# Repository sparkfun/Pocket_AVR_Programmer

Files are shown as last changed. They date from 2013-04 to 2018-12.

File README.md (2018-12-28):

Pocket AVR Programmer
=====================

[Pocket AVR Programmer  
*Pocket AVR Programmer (PGM-09825)*](https://www.sparkfun.com/products/9825)

This is a simple to use USB AVR programmer, that works with ATmega168 and ATmega328 and should work well
with all the AVR micros supported by AVRDUDE.

Repository Contents
-------------------
* **/Enclosure** - 3D model of enclosure for this (.stl).
* **/Drivers** - Windows 7 drivers for use with this programmer. 
* **/Firmware** - Firmware that ships on the Pocket AVR Programmer.
* **/Hardware** - All Eagle design files (.brd, .sch).

Documentation
--------------
* **[Hookup Guide](https://learn.sparkfun.com/tutorials/pocket-avr-programmer-hookup-guide)** - Basic hookup guide for the Pocket AVR Programmer. 
* **[Installing an Arduino Bootloader](https://learn.sparkfun.com/tutorials/installing-an-arduino-bootloader)**  - Example of installing an Arduino bootloader on an Atmega328P-based microcontrollers (i.e. Arduino Uno and RedBoard Programmed with Arduino) through the Arduino IDE and command line using avrdude.

License Information
-------------------
The hardware is released under [Creative Commons Share-alike 3.0](http://creativecommons.org/licenses/by-sa/3.0/).
The firmware is based off of:
* [USBtiny](http://dicks.home.xs4all.nl/avr/usbtiny/index.html) by Dick Streefland
* [USBtinyISP](http://www.ladyada.net/make/usbtinyisp/) by Limor Fried and is a collaboration with Limor Fried currently.

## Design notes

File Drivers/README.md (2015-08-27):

Pocket AVR Programmer Drivers
=============================

Folder Contents
-------------------
Windows 7, 8, 8.1, 10 Driver files for the AVR Pocket Programmer. Original Source of files: http://www.adafruit.com/downloads/usbtiny_signed_8.zip

Please note you no longer need to verify the security signature for the drivers.

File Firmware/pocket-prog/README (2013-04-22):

USBtiny
=======

USBtiny is a software implementation of the USB low-speed protocol for
the Atmel ATtiny microcontrollers. Of course, it will also work on the
ATmega series. The software is written for an AVR clocked at 12 MHz.
At this frequency, each bit on the USB bus takes 8 clock cycles, and
with a lot of trickery, it is possible to decode and encode the USB
waveforms by software. The USB driver needs between 1300 and 1400
bytes of flash space (excluding the optional identification strings),
depending on the configuration and compiler version, and 46 bytes RAM
(excluding stack space). The C interface consists of 3 to 5 functions,
depending on the configuration.

Implementation
==============

USB uses two differential data signals, D+ and D-, which are normally
complementary. However, the end of a packet is signalled by pulling
both signals low. Data is not transmitted directly on the USB bus, it
is NRZI encoded first. This means that a "0" bit is encoded as a bit
change, and a "1" bit is encoded as no bit change. After 6 "1" bits,
"bit stuffing" takes place to force a change on the USB signal lines.

The software is interrupt driven: the start of a USB packet triggers
an interrupt. The interrupt handler synchronizes with the sync byte,
removes the NRZI encoding and bit stuffing, and stores the packed in
one of the two RAM buffers. Two buffers are used so that the next
packet can be received while the current one is being processed.
Depending on the packet type, a reply packed may be sent back
immediately in the interrupt handler.

The rest of the USB driver is written in C. A usb_poll() function
must to be called periodically to poll for incoming packets. Only a
single endpoint is supported at the moment. Standard control requests
are directly handled by the USB driver. Other SETUP requests are
forwarded to a user-supplied function usb_setup(). Support for large
replies and OUT control requests is optional, see usbtiny.h.

To use the USB driver in your own application, you need to configure
the macros in usbtiny.h, and provide a function usb_setup() to handle
SETUP control packets. Optionally, you need to provide the functions
usb_in() and usb_out(). Your code needs to call the initialization
function usb_init() at program startup, and usb_poll() at regular
intervals. The AVR device type and the upload command should be
configured at the top of the Makefile.

Other USB projects
==================

This software was inspired by two similar USB projects for the AVR:

  http://www.cesko.host.sk/IgorPlugUSB/IgorPlug-USB%20(AVR)_eng.htm
  http://www.obdev.at/products/avrusb/index.html

My version has the advantage that you have more freedom over which I/O
pins to use for the D+ and D- USB signals. You don't need to use bit 0
for the D+ signal. The only restriction is that both signals should be
on the same I/O port. When you select a pin for D+ that can also
generate an interrupt, only two I/O pins are required. The pin-change
interrupt is deliberately not used, so that it remains available for
other uses.

Another improvement is that the CRC calculation is faster, because it
uses a lookup table. A bit-wise calculation turned out to be too slow
for the USB controller in my laptop. For instance, the obdev code
worked fine on my desktop computer, but not on my laptop.

Apart from these advantages, I think that my code is more readable and
easier to configure, but that impression may be caused by a mild form
of the NIH syndrome that I'm suffering from. In any case, I learned a
lot about the USB protocol, and writing the interrupt handler was a
nice puzzle.

Hardware
========

The AVR must be clocked with an external 12 MHz crystal. For an
ATtiny2313, this means that the low fuse byte must be reprogrammed,
for instance to 0xff. I also recommend to enable the BOD circuit,
when available. For the ATtiny2313, this means programming the high
fuse byte to 0xdb (BOD level is 2.7V).

The USB data signals are specified at 3.3V. The easiest way to
accomplish this is to use a 3.3V power supply for the AVR. However,
driving the USB signals with 5V seems to work as well in most cases,
which may be more convenient when you need to interface to 5V
peripherals. According to the USB specification, a device should not
be damaged by 5V signals. I've been running the AVR and USB bus at 5V,
and haven't encounter any problems so far, but I have some reports
of Viao laptops that do not work with 5V signals. In that case, you
can reduce the voltage of the USB data signals by adding 3V6 zener
diodes from the data signals to ground.

USBtiny SPI converter
=====================

My first USBtiny application is a USB to SPI (Serial Programming
Interface) converter. The SPI signals are connected to a female DB-25
connecter, so that the converter can be plugged onto my AVR parallel
port programmer. Because the most important parallel port signals are
connected to the DB-25 connecter, the same hardware (with different
firmware) could be used to control other parallel port devices. That
is also the reason why I connected the ACK signal to the INT1 pin.
I didn't bother to put capacitors on the crystal, but they are
recommended for reliable operation. The software, the schematic and
a Python test script can be found in the "spi" subdirectory.

The circuit may be powered via the diode at pin 14 of the DB-25
connector to enable reprograming the ATtiny2313 in-system. This
requires an adaptor cable between another SPI programmer and a DB-25
male connector with the following connections:

  SPI  DB25
  ---  ----
  GND    25
  VCC    14
  RESET  13
  SCK     9
  MISO    8
  MOSI    7

Bit-banging the SPI signals via USB turned out to be very slow. To get
reasonable programming speeds, I've moved the SPI algorithm into the
AVR. This means that you can send a 32-bit SPI command in a single USB
packet. In addition, you can read or write up to 255 bytes from/to
flash or EEPROM in a single control transfer.

The subdirectory "patches" contains a patch for avrdude-5.1 that adds
support for controlling this SPI converter. The programmer name is
"usbtiny". You can use the -B option or the "sck" command to specify
the minimum SCK period in microseconds (range: 1..250, default: 10).

USBtiny LIRC compatible IR receiver and LCD controller
======================================================

A second USBtiny application is a receiver for infrared remote
controls that can be used with the LIRC package (http://www.lirc.org/).
The firmware stores the mark/space timings from a TSOP1738 IR decoder
in a buffer that is polled by a LIRC device driver. As a visual
feedback, a LED is flashed when a signal is being received. As an
additional (optional) feature, a 2x16 LCD display is attached to PORTB.
You can control the display via the USB bus. The software, the schematic
and a Python test script can be found in the "ir" subdirectory.
A pull-down resistor at PB3 prevents a hang in the LCD initialization
code when no LCD is attached to PORTB. You can disable the LCD code by
setting the LCD_PRESENT macro in main.c to 0.

I adopted the "IgorPlug-USB" protocol, so that the existing LIRC
device driver "igorplugusb" could be used without modifications.
Nevertheless, a patch for lirc-0.8.0 is included in the "patches"
subdirectory, with the following modifications:
1) An increase of the sample rate from 10 to 100 times per second.
   This is not required, but improves the responsiveness and repeat
   behavior for some remote controls.
2) A fix from Reinhard Max to get correct gap timings.
3) A compilation fix for the latest 2.6 Linux kernels.

Tools
=====

The software was developed on a Linux system. In addition to standard
tools like GNU make, you need the AVR versions of gcc, binutils and
glibc to build the code: On a Debian/Ubuntu system, you can apt-get
the following packages:

  gcc-avr
  binutils-avr
  avr-libc

To upload the code to an AVR, I use avrdude with a parallel port
programmer.

I initially used gcc-3.4.3 with the -Os option, which generates
reasonable compact code. Unfortunately, newer versions like gcc-4.1.0
generate about 10% more code, and as a result, the application code
did not fit in 2K anymore. To make it fit, I had to remove the optional
vendor and device strings, by undefining the USBTINY_VENDOR_NAME and
USBTINY_DEVICE_NAME macros.

The schematics were created with gschem, which is part of the gEDA
package. The conversion to Postscript is done with a script that
invokes gschem non-interactively.

The "util" and application code subdirectories each contain their own
Makefile. In addition, there is a global Makefile that recursively
invokes all other Makefiles.

Host software
=============

The subdirectory "utils" contains a Python module "usbtiny.py" that
defines a class USBtiny that can be used to communicate with the
USBtiny firmware. This class is used by the test scripts.

The usbtiny.py module uses a Python wrapper around libusb that is
generated by "swig". Type "make" to build the wrapper. Of course, you
need to have swig, libusb and libusb-dev installed on your system.

Libusb needs appropriate permissions to open a USB device. This means
that you either have to run the scripts as "root", or you should
configure the hotplug or udev system to relax the permissions of the
device file created under /proc/bus/usb/ when the device is plugged
in. With udev, you can change the permissions by adding a rule like

  SUBSYSTEM=="usb_device", MODE="0666" 

to the udev rules in /etc/udev/rules.d/

License
=======

The USBtiny software is licensed under the terms of the GNU General
Public License as published by the Free Software Foundation, either
version 2 of the license, or (at your option) any later version. A
copy of the GPL version 2 license can be found in the file COPYING.

Author & website
================

Dick Streefland <dick@streefland.net>

http://www.google.com/search?btnI&q=webtag_net_streefland_avr_usbtiny

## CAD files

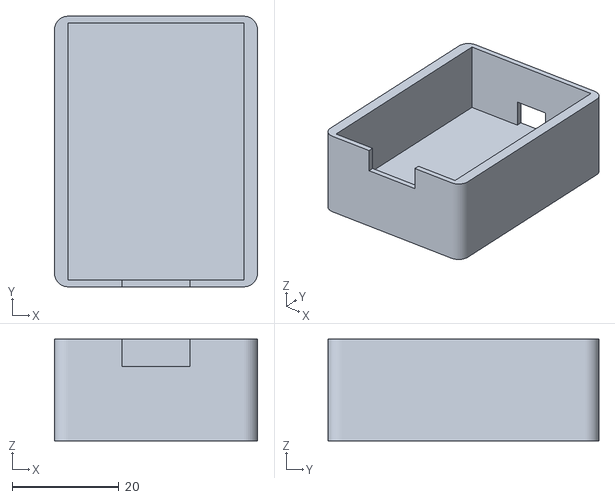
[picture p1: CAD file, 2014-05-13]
Enclosure/avr.STL
38.1 x 50.8 x 19.1

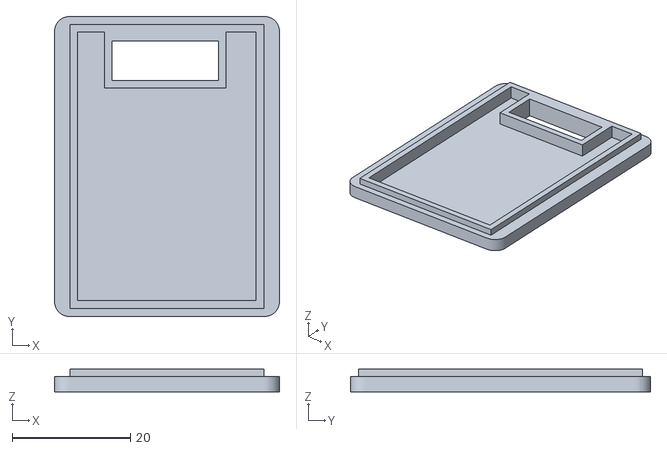
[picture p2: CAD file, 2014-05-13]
Enclosure/lid.STL
38.1 x 50.8 x 3.81

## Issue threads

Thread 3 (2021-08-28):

Error when trying to compile  Pocket_AVR_Programmer firmware

hansake, 2021-08-28:
When trying to compile the Pocket_AVR_Programmer firmware I get:
~/AVR/Pocket_AVR_Programmer-master/Firmware/pocket-prog/spi$ make all
avr-gcc -Os -g -Wall -I. -I../usbtiny  -mmcu=attiny2313 -c ../usbtiny/crc.S
In file included from ../usbtiny/crc.S:22:0:
../usbtiny/def.h:39:13: error: attempt to use poisoned "SIG_INT0"
 #if defined SIG_INT0
             ^
make: *** [../usbtiny/common.mk:56: crc.o] Error 1

I am using gcc/avr/5.4.0
Any idea what is wrong?
/Hans-Åke

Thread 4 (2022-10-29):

3.3 V and 5 V tolerant design

gsauthof, 2022-10-29:
Reading through the Sparkfun hook-up guide I was surprised to find a recommendation for a Sparkfun Logic Level Converter since the original schematics read like it would be superfluous. I left a comment under the [guide](https://learn.sparkfun.com/tutorials/pocket-avr-programmer-hookup-guide/discuss) and was recently informed that this issue tracker would be a better place for such feedback.

For reference my comment (posted it in May 2022):

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

---

I also asked about this on the Electronics SE site. I think that the [answer of User 'Justme'](https://electronics.stackexchange.com/a/623231) contains some additional useful feedback you might want to consider in a future hardware revision.

I'll reproduce the relevant part here, even if the tone is a bit harsh, since the raised points might still be of interest to you:

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

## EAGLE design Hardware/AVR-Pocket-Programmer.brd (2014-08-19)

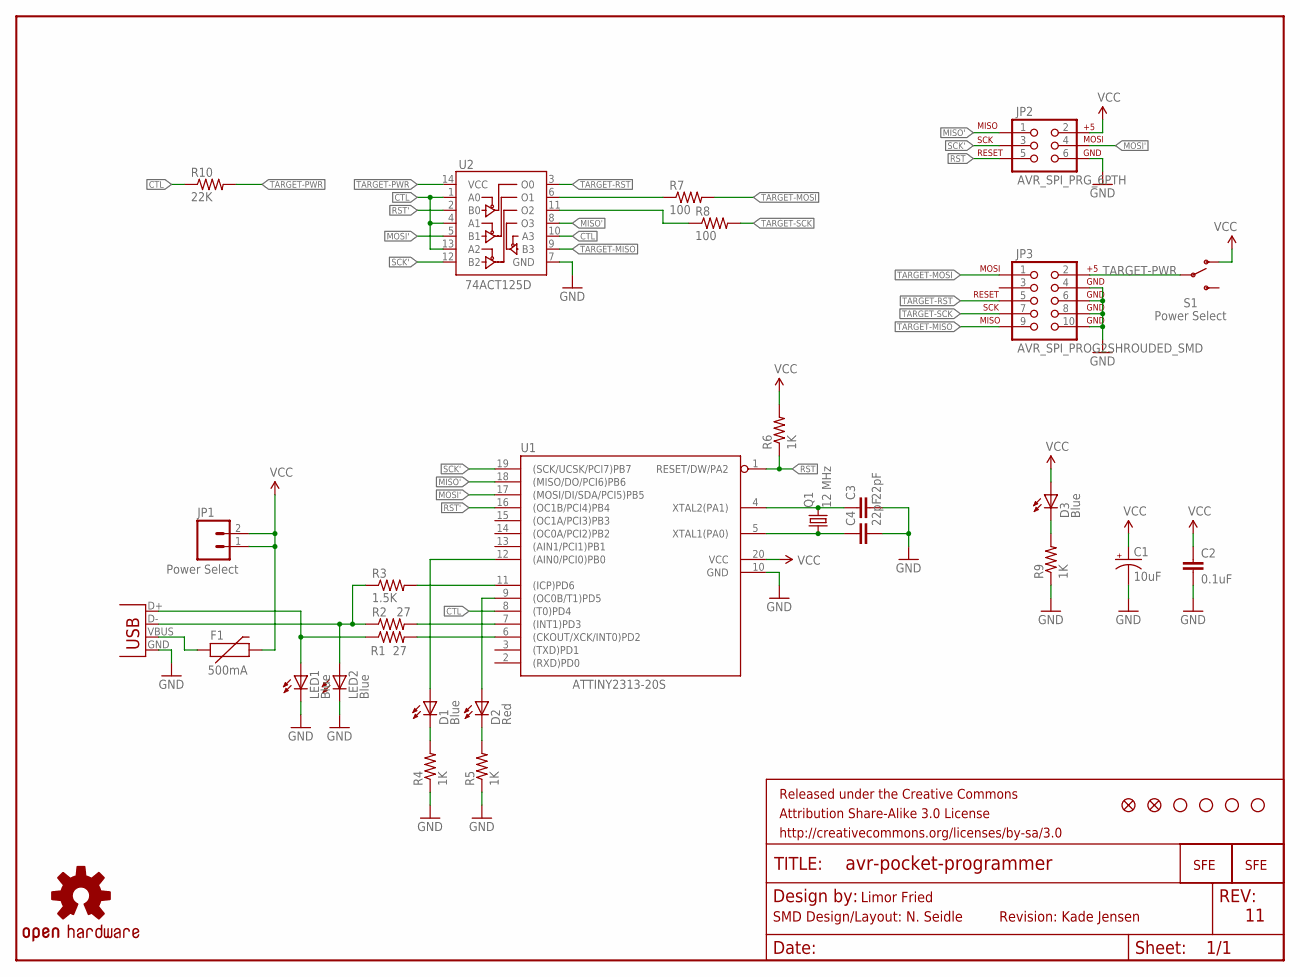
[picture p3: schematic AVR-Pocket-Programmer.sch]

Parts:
C1: 10uF; EIA3216
C2: 0.1uF; 0603-CAP
C3, C4: 22pF; 0603-CAP
D1, D3: Blue; LED-0603
D2: Red; LED-0603
F1: 500mA; PTC-1206-WIDE
FRAME1: FRAME-LETTER; CREATIVE_COMMONS
JP1: Power Select; 1X02
JP2: AVR_SPI_PRG_6PTH; 2X3
JP3: AVR_SPI_PROG2SHROUDED_SMD; 2X5-SHROUDED_SMD
LED1, LED2: Blue; LED-0603
LOGO1: OSHW-LOGOM; OSHW-LOGO-M
Q1: 12 MHz; CRYSTAL-SMD-5X3
R1, R2: 27; 0603-RES
R3: 1.5K; 0603-RES
R4, R5, R6, R9: 1K; 0603-RES
R7, R8: 100; 0603-RES
R10: 22K; 0603-RES
S1: Power Select; AYZ0202
U1: ATTINY2313-20S; SO20L
U2: 74ACT125D; SO014
U$1, U$3, U$4, U$5: STAND-OFF
U$2: LOGO-SFESK; SFE-LOGO-FLAME
U$6, U$7: FIDUCIAL1X2; FIDUCIAL-1X2
U$8: LOGO-SFENEW; SFE-NEW-WEBLOGO
X2: USBSMD; USB-MINIB

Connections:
CTL: R10.1, U1.8 ((T0)PD4), U2.1 (A0), U2.4 (A1), U2.10 (A3), U2.13 (A2)
D+: LED1.A, R1.1, X2.D+
D-: LED2.A, R2.1, R3.1, X2.D-
GND: C1.C (-), C2.2, C3.2, C4.2, JP2.6, JP3.4, JP3.6, JP3.8, JP3.10, LED1.C, LED2.C, R4.1, R5.1, R9.1, U1.10 (GND), U2.7 (GND), X2.GND
MISO': JP2.1, U1.18 ((MISO/DO/PCI6)PB6), U2.8 (O3)
MOSI': JP2.4, U1.17 ((MOSI/DI/SDA/PCI5)PB5), U2.5 (B1)
unnamed: R3.2, U1.11 ((ICP)PD6)
unnamed: D2.A, U1.9 ((OC0B/T1)PD5)
unnamed: D3.C, R9.2
unnamed: F1.1, X2.VBUS
unnamed: C3.1, Q1.3 (2), U1.4 (XTAL2(PA1))
unnamed: C4.1, Q1.1, U1.5 (XTAL1(PA0))
unnamed: D1.A, U1.12 ((AIN0/PCI0)PB0)
unnamed: D1.C, R4.2
unnamed: D2.C, R5.2
unnamed: R7.1, U2.6 (O1)
unnamed: R8.1, U2.11 (O2)
PD+: R1.2, U1.6 ((CKOUT/XCK/INT0)PD2)
PD-: R2.2, U1.7 ((INT1)PD3)
RST: JP2.5, R6.1, U1.1 (RESET/DW/PA2)
RST': U1.16 ((OC1B/PCI4)PB4), U2.2 (B0)
SCK': JP2.3, U1.19 ((SCK/UCSK/PCI7)PB7), U2.12 (B2)
TARGET-MISO: JP3.9, U2.9 (B3)
TARGET-MOSI: JP3.1, R7.2
TARGET-PWR: JP3.2, R10.2, S1.2, U2.14 (VCC)
TARGET-RST: JP3.5, U2.3 (O0)
TARGET-SCK: JP3.7, R8.2
VCC: C1.A (+), C2.1, D3.A, F1.2, JP1.1, JP1.2, JP2.2, R6.2, S1.1 (O), U1.20 (VCC)

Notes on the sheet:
Limor Fried
SMD Design/Layout: N. Seidle
Revision: Kade Jensen

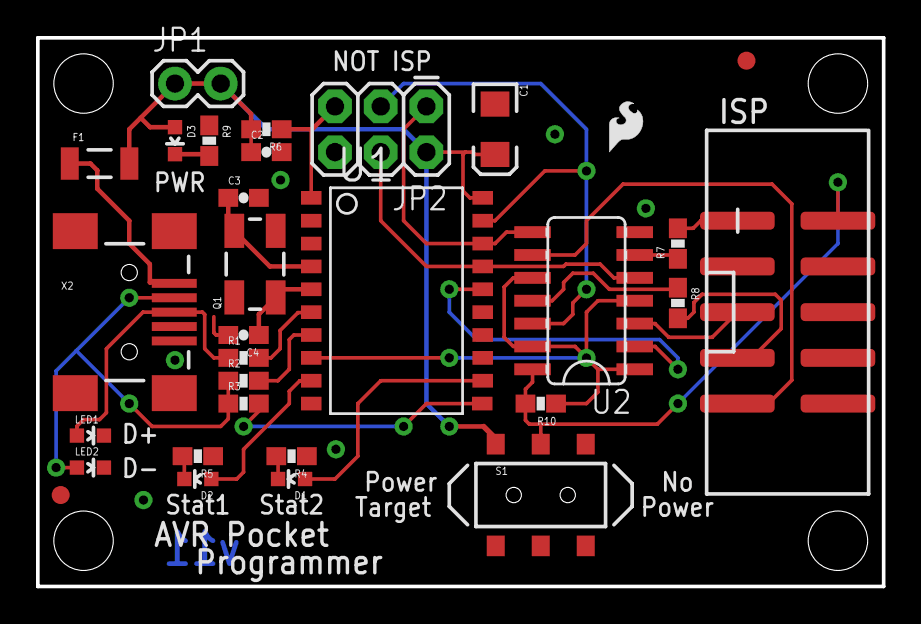
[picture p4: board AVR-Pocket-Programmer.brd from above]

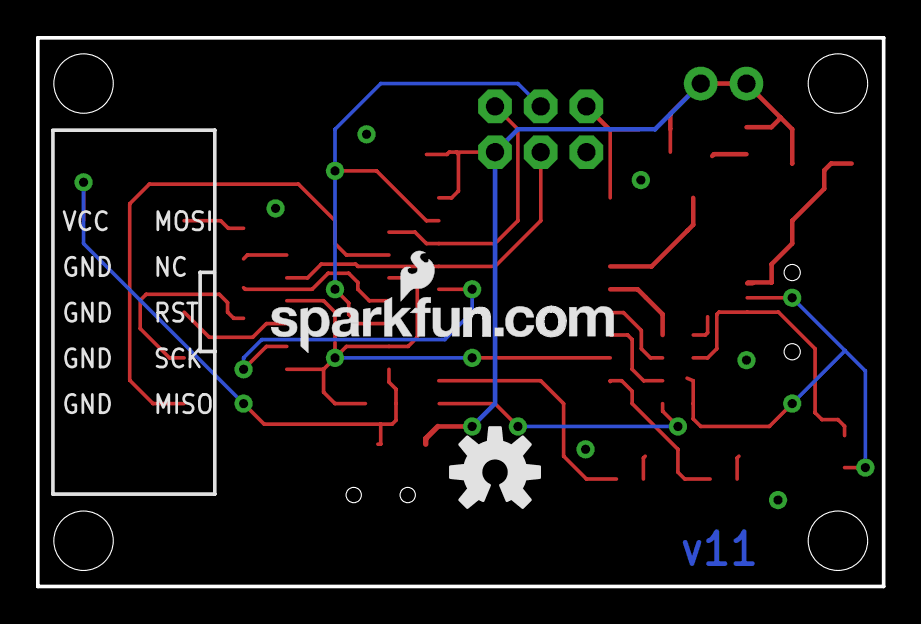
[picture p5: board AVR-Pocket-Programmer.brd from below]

Board: 2 copper layers, 47.0 x 30.5 mm, 38 parts (2 on the bottom side), 28 nets.

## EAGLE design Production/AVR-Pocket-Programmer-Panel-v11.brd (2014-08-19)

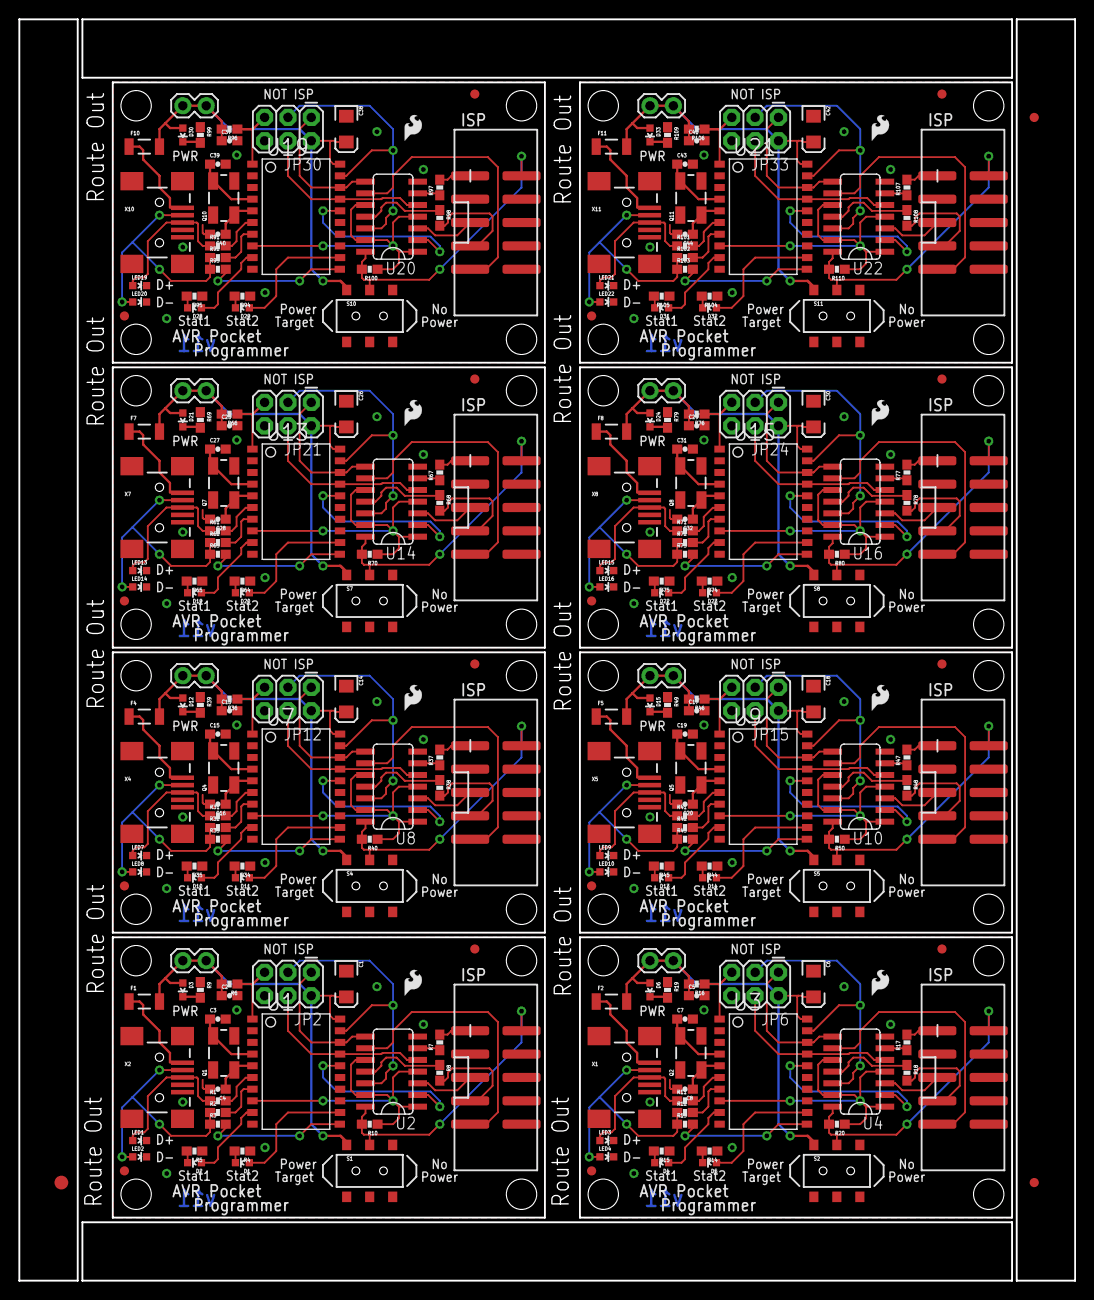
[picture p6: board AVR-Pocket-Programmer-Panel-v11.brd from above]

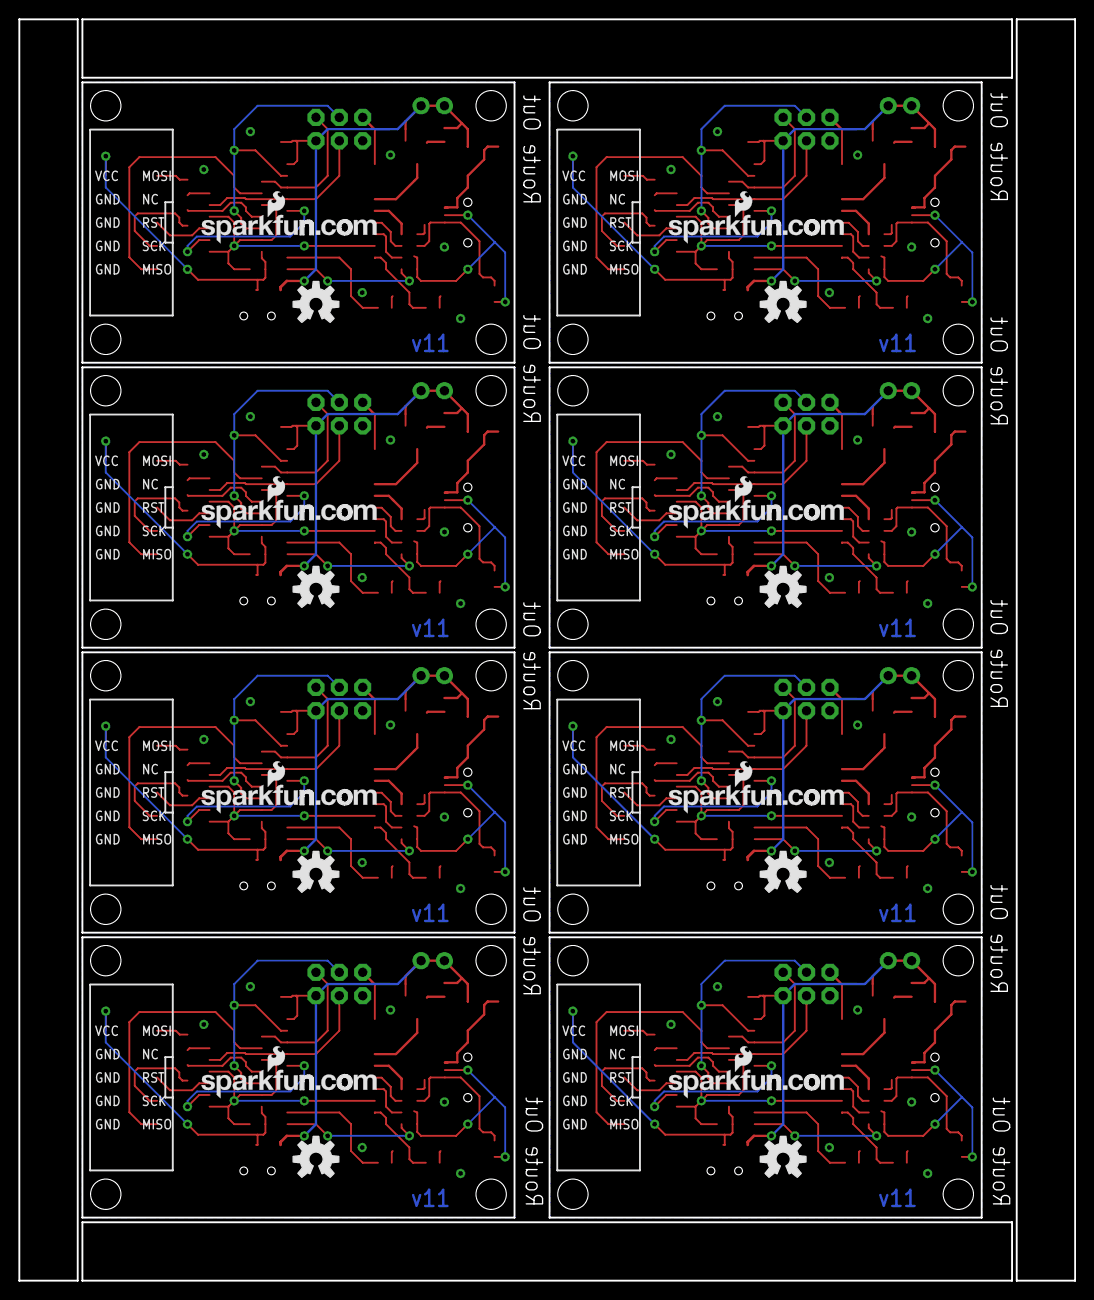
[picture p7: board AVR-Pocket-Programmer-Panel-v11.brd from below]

Board: 2 copper layers, 114.8 x 137.2 mm, 299 parts (16 on the bottom side), 224 nets.

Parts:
C1, C6, C14, C18, C26, C30, C38, C42: 10uF; EIA3216
C2, C5, C13, C17, C25, C29, C37, C41: 0.1uF; 0603-CAP
C3, C4, C7, C8, C15, C16, C19, C20, C27, C28, C31, C32, C39, C40, C43, C44: 22pF; 0603-CAP
D1, D3, D5, D6, D11, D12, D14, D15, D20, D21, D23, D24, D29, D30, D32, D33: Blue; LED-0603
D2, D4, D10, D13, D19, D22, D28, D31: Red; LED-0603
E$1: FIDUCIAL-1.5X3
E$5, E$6: FIDUCIAL-1X2
F1, F2, F4, F5, F7, F8, F10, F11: 500mA; PTC-1206-WIDE
JP1, JP4, JP10, JP13, JP19, JP22, JP28, JP31: Power Select; 1X02
JP2, JP6, JP12, JP15, JP21, JP24, JP30, JP33: AVR_SPI_PRG_6PTH; 2X3
JP3, JP5, JP11, JP14, JP20, JP23, JP29, JP32: AVR_SPI_PROG2SHROUDED_SMD; 2X5-SHROUDED_SMD
LED1, LED2, LED3, LED4, LED7, LED8, LED9, LED10, LED13, LED14, LED15, LED16, LED19, LED20, LED21, LED22: Blue; LED-0603
LOGO1, LOGO2, LOGO4, LOGO5, LOGO7, LOGO8, LOGO10, LOGO11: OSHW-LOGOM; OSHW-LOGO-M
Q1, Q2, Q4, Q5, Q7, Q8, Q10, Q11: 12 MHz; CRYSTAL-SMD-5X3
R1, R2, R11, R12, R31, R32, R41, R42, R61, R62, R71, R72, R91, R92, R101, R102: 27; 0603-RES
R3, R13, R33, R43, R63, R73, R93, R103: 1.5K; 0603-RES
R4, R5, R6, R9, R14, R15, R16, R19, R34, R35, R36, R39, R44, R45, R46, R49, R64, R65, R66, R69, R74, R75, R76, R79, R94, R95, R96, R99, R104, R105, R106, R109: 1K; 0603-RES
R7, R8, R17, R18, R37, R38, R47, R48, R67, R68, R77, R78, R97, R98, R107, R108: 100; 0603-RES
R10, R20, R40, R50, R70, R80, R100, R110: 22K; 0603-RES
S1, S2, S4, S5, S7, S8, S10, S11: Power Select; AYZ0202
U1, U3, U7, U9, U13, U15, U19, U21: ATTINY2313-20S; SO20L
U2, U4, U8, U10, U14, U16, U20, U22: 74ACT125D; SO014
U$1, U$3, U$4, U$5, U$9, U$10, U$11, U$12, U$25, U$26, U$27, U$28, U$33, U$34, U$35, U$36, U$49, U$50, U$51, U$52, U$57, U$58, U$59, U$60, U$73, U$74, U$75, U$76, U$81, U$82, U$83, U$84: STAND-OFF
U$2, U$16, U$32, U$40, U$56, U$64, U$80, U$88: LOGO-SFESK; SFE-LOGO-FLAME
U$6, U$7, U$13, U$14, U$29, U$30, U$37, U$38, U$53, U$54, U$61, U$62, U$77, U$78, U$85, U$86: FIDUCIAL1X2; FIDUCIAL-1X2
U$8, U$15, U$31, U$39, U$55, U$63, U$79, U$87: LOGO-SFENEW; SFE-NEW-WEBLOGO
X1, X2, X4, X5, X7, X8, X10, X11: USBSMD; USB-MINIB

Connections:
CTL: R10.1, U1.8, U2.1, U2.4, U2.10, U2.13
CTL1: R20.1, U3.8, U4.1, U4.4, U4.10, U4.13
CTL3: R40.1, U7.8, U8.1, U8.4, U8.10, U8.13
CTL4: R50.1, U9.8, U10.1, U10.4, U10.10, U10.13
CTL6: R70.1, U13.8, U14.1, U14.4, U14.10, U14.13
CTL7: R80.1, U15.8, U16.1, U16.4, U16.10, U16.13
CTL9: R100.1, U19.8, U20.1, U20.4, U20.10, U20.13
CTL10: R110.1, U21.8, U22.1, U22.4, U22.10, U22.13
D+: LED1.A, R1.1, X2.D+
D+1: LED3.A, R11.1, X1.D+
D+3: LED7.A, R31.1, X4.D+
D+4: LED9.A, R41.1, X5.D+
D+6: LED13.A, R61.1, X7.D+
D+7: LED15.A, R71.1, X8.D+
D+9: LED19.A, R91.1, X10.D+
D+10: LED21.A, R101.1, X11.D+
D-: LED2.A, R2.1, R3.1, X2.D-
D-1: LED4.A, R12.1, R13.1, X1.D-
D-3: LED8.A, R32.1, R33.1, X4.D-
D-4: LED10.A, R42.1, R43.1, X5.D-
D-6: LED14.A, R62.1, R63.1, X7.D-
D-7: LED16.A, R72.1, R73.1, X8.D-
D-9: LED20.A, R92.1, R93.1, X10.D-
D-10: LED22.A, R102.1, R103.1, X11.D-
GND: C1.C, C2.2, C3.2, C4.2, JP2.6, JP3.4, JP3.6, JP3.8, JP3.10, LED1.C, LED2.C, R4.1, R5.1, R9.1, U1.10, U2.7, X2.GND
GND1: C5.2, C6.C, C7.2, C8.2, JP5.4, JP5.6, JP5.8, JP5.10, JP6.6, LED3.C, LED4.C, R14.1, R15.1, R19.1, U3.10, U4.7, X1.GND
GND3: C13.2, C14.C, C15.2, C16.2, JP11.4, JP11.6, JP11.8, JP11.10, JP12.6, LED7.C, LED8.C, R34.1, R35.1, R39.1, U7.10, U8.7, X4.GND
GND4: C17.2, C18.C, C19.2, C20.2, JP14.4, JP14.6, JP14.8, JP14.10, JP15.6, LED9.C, LED10.C, R44.1, R45.1, R49.1, U9.10, U10.7, X5.GND
GND6: C25.2, C26.C, C27.2, C28.2, JP20.4, JP20.6, JP20.8, JP20.10, JP21.6, LED13.C, LED14.C, R64.1, R65.1, R69.1, U13.10, U14.7, X7.GND
GND7: C29.2, C30.C, C31.2, C32.2, JP23.4, JP23.6, JP23.8, JP23.10, JP24.6, LED15.C, LED16.C, R74.1, R75.1, R79.1, U15.10, U16.7, X8.GND
GND9: C37.2, C38.C, C39.2, C40.2, JP29.4, JP29.6, JP29.8, JP29.10, JP30.6, LED19.C, LED20.C, R94.1, R95.1, R99.1, U19.10, U20.7, X10.GND
GND10: C41.2, C42.C, C43.2, C44.2, JP32.4, JP32.6, JP32.8, JP32.10, JP33.6, LED21.C, LED22.C, R104.1, R105.1, R109.1, U21.10, U22.7, X11.GND
MISO': JP2.1, U1.18, U2.8
MISO'1: JP6.1, U3.18, U4.8
MISO'3: JP12.1, U7.18, U8.8
MISO'4: JP15.1, U9.18, U10.8
MISO'6: JP21.1, U13.18, U14.8
MISO'7: JP24.1, U15.18, U16.8
MISO'9: JP30.1, U19.18, U20.8
MISO'10: JP33.1, U21.18, U22.8
MOSI': JP2.4, U1.17, U2.5
MOSI'1: JP6.4, U3.17, U4.5
MOSI'3: JP12.4, U7.17, U8.5
MOSI'4: JP15.4, U9.17, U10.5
MOSI'6: JP21.4, U13.17, U14.5
MOSI'7: JP24.4, U15.17, U16.5
MOSI'9: JP30.4, U19.17, U20.5
MOSI'10: JP33.4, U21.17, U22.5
unnamed: R3.2, U1.11
unnamed: D2.A, U1.9
unnamed: D3.C, R9.2
unnamed: F1.1, X2.VBUS
unnamed: C3.1, Q1.3, U1.4
unnamed: C4.1, Q1.1, U1.5
unnamed: R13.2, U3.11
unnamed: D4.A, U3.9
unnamed: D5.A, U3.12
unnamed: D5.C, R14.2
unnamed: D4.C, R15.2
unnamed: R17.1, U4.6
unnamed: R18.1, U4.11
unnamed: D6.C, R19.2
unnamed: F2.1, X1.VBUS
unnamed: C7.1, Q2.3, U3.4
unnamed: D1.A, U1.12
unnamed: D1.C, R4.2
unnamed: D2.C, R5.2
unnamed: C8.1, Q2.1, U3.5
unnamed: R7.1, U2.6
unnamed: R8.1, U2.11
unnamed: R33.2, U7.11
unnamed: D10.A, U7.9
unnamed: D11.A, U7.12
unnamed: D11.C, R34.2
unnamed: D10.C, R35.2
unnamed: R37.1, U8.6
unnamed: R38.1, U8.11
unnamed: D12.C, R39.2
unnamed: F4.1, X4.VBUS
unnamed: C15.1, Q4.3, U7.4
unnamed: C16.1, Q4.1, U7.5
unnamed: R43.2, U9.11
unnamed: D13.A, U9.9
unnamed: D14.A, U9.12
unnamed: D14.C, R44.2
unnamed: D13.C, R45.2
unnamed: R47.1, U10.6
unnamed: R48.1, U10.11
unnamed: D15.C, R49.2
unnamed: F5.1, X5.VBUS
unnamed: C19.1, Q5.3, U9.4
unnamed: C20.1, Q5.1, U9.5
unnamed: R63.2, U13.11
unnamed: D19.A, U13.9
unnamed: D20.A, U13.12
unnamed: D20.C, R64.2
unnamed: D19.C, R65.2
unnamed: R67.1, U14.6
unnamed: R68.1, U14.11
unnamed: D21.C, R69.2
unnamed: F7.1, X7.VBUS
unnamed: C27.1, Q7.3, U13.4
unnamed: C28.1, Q7.1, U13.5
unnamed: R73.2, U15.11
unnamed: D22.A, U15.9
unnamed: D23.A, U15.12
unnamed: D23.C, R74.2
unnamed: D22.C, R75.2
unnamed: R77.1, U16.6
unnamed: R78.1, U16.11
unnamed: D24.C, R79.2
unnamed: F8.1, X8.VBUS
unnamed: C31.1, Q8.3, U15.4
unnamed: C32.1, Q8.1, U15.5
unnamed: R93.2, U19.11
unnamed: D28.A, U19.9
unnamed: D29.A, U19.12
unnamed: D29.C, R94.2
unnamed: D28.C, R95.2
unnamed: R97.1, U20.6
unnamed: R98.1, U20.11
unnamed: D30.C, R99.2
unnamed: F10.1, X10.VBUS
unnamed: C39.1, Q10.3, U19.4
unnamed: C40.1, Q10.1, U19.5
unnamed: R103.2, U21.11
unnamed: D31.A, U21.9
unnamed: D32.A, U21.12
unnamed: D32.C, R104.2
unnamed: D31.C, R105.2
unnamed: R107.1, U22.6
unnamed: R108.1, U22.11
unnamed: D33.C, R109.2
unnamed: F11.1, X11.VBUS
unnamed: C43.1, Q11.3, U21.4
unnamed: C44.1, Q11.1, U21.5
PD+: R1.2, U1.6
PD+1: R11.2, U3.6
PD+3: R31.2, U7.6
PD+4: R41.2, U9.6
PD+6: R61.2, U13.6
PD+7: R71.2, U15.6
PD+9: R91.2, U19.6
PD+10: R101.2, U21.6
PD-: R2.2, U1.7
PD-1: R12.2, U3.7
PD-3: R32.2, U7.7
PD-4: R42.2, U9.7
PD-6: R62.2, U13.7
PD-7: R72.2, U15.7
PD-9: R92.2, U19.7
PD-10: R102.2, U21.7
RST: JP2.5, R6.1, U1.1
RST1: JP6.5, R16.1, U3.1
RST3: JP12.5, R36.1, U7.1
RST4: JP15.5, R46.1, U9.1
RST6: JP21.5, R66.1, U13.1
RST7: JP24.5, R76.1, U15.1
RST9: JP30.5, R96.1, U19.1
RST10: JP33.5, R106.1, U21.1
RST': U1.16, U2.2
RST'1: U3.16, U4.2
RST'3: U7.16, U8.2
RST'4: U9.16, U10.2
RST'6: U13.16, U14.2
RST'7: U15.16, U16.2
RST'9: U19.16, U20.2
RST'10: U21.16, U22.2
SCK': JP2.3, U1.19, U2.12
SCK'1: JP6.3, U3.19, U4.12
SCK'3: JP12.3, U7.19, U8.12
SCK'4: JP15.3, U9.19, U10.12
SCK'6: JP21.3, U13.19, U14.12
SCK'7: JP24.3, U15.19, U16.12
SCK'9: JP30.3, U19.19, U20.12
SCK'10: JP33.3, U21.19, U22.12
TARGET-MISO: JP3.9, U2.9
TARGET-MISO1: JP5.9, U4.9
TARGET-MISO3: JP11.9, U8.9
TARGET-MISO4: JP14.9, U10.9
TARGET-MISO6: JP20.9, U14.9
TARGET-MISO7: JP23.9, U16.9
TARGET-MISO9: JP29.9, U20.9
TARGET-MISO10: JP32.9, U22.9
TARGET-MOSI: JP3.1, R7.2
TARGET-MOSI1: JP5.1, R17.2
TARGET-MOSI3: JP11.1, R37.2
TARGET-MOSI4: JP14.1, R47.2
TARGET-MOSI6: JP20.1, R67.2
TARGET-MOSI7: JP23.1, R77.2
TARGET-MOSI9: JP29.1, R97.2
TARGET-MOSI10: JP32.1, R107.2
TARGET-PWR: JP3.2, R10.2, S1.2, U2.14
TARGET-PWR1: JP5.2, R20.2, S2.2, U4.14
TARGET-PWR3: JP11.2, R40.2, S4.2, U8.14
TARGET-PWR4: JP14.2, R50.2, S5.2, U10.14
TARGET-PWR6: JP20.2, R70.2, S7.2, U14.14
TARGET-PWR7: JP23.2, R80.2, S8.2, U16.14
TARGET-PWR9: JP29.2, R100.2, S10.2, U20.14
TARGET-PWR10: JP32.2, R110.2, S11.2, U22.14
TARGET-RST: JP3.5, U2.3
TARGET-RST1: JP5.5, U4.3
TARGET-RST3: JP11.5, U8.3
TARGET-RST4: JP14.5, U10.3
TARGET-RST6: JP20.5, U14.3
TARGET-RST7: JP23.5, U16.3
TARGET-RST9: JP29.5, U20.3
TARGET-RST10: JP32.5, U22.3
TARGET-SCK: JP3.7, R8.2
TARGET-SCK1: JP5.7, R18.2
TARGET-SCK3: JP11.7, R38.2
TARGET-SCK4: JP14.7, R48.2
TARGET-SCK6: JP20.7, R68.2
TARGET-SCK7: JP23.7, R78.2
TARGET-SCK9: JP29.7, R98.2
TARGET-SCK10: JP32.7, R108.2
VCC: C1.A, C2.1, D3.A, F1.2, JP1.1, JP1.2, JP2.2, R6.2, S1.1, U1.20
VCC1: C5.1, C6.A, D6.A, F2.2, JP4.1, JP4.2, JP6.2, R16.2, S2.1, U3.20
VCC3: C13.1, C14.A, D12.A, F4.2, JP10.1, JP10.2, JP12.2, R36.2, S4.1, U7.20
VCC4: C17.1, C18.A, D15.A, F5.2, JP13.1, JP13.2, JP15.2, R46.2, S5.1, U9.20
VCC6: C25.1, C26.A, D21.A, F7.2, JP19.1, JP19.2, JP21.2, R66.2, S7.1, U13.20
VCC7: C29.1, C30.A, D24.A, F8.2, JP22.1, JP22.2, JP24.2, R76.2, S8.1, U15.20
VCC9: C37.1, C38.A, D30.A, F10.2, JP28.1, JP28.2, JP30.2, R96.2, S10.1, U19.20
VCC10: C41.1, C42.A, D33.A, F11.2, JP31.1, JP31.2, JP33.2, R106.2, S11.1, U21.20

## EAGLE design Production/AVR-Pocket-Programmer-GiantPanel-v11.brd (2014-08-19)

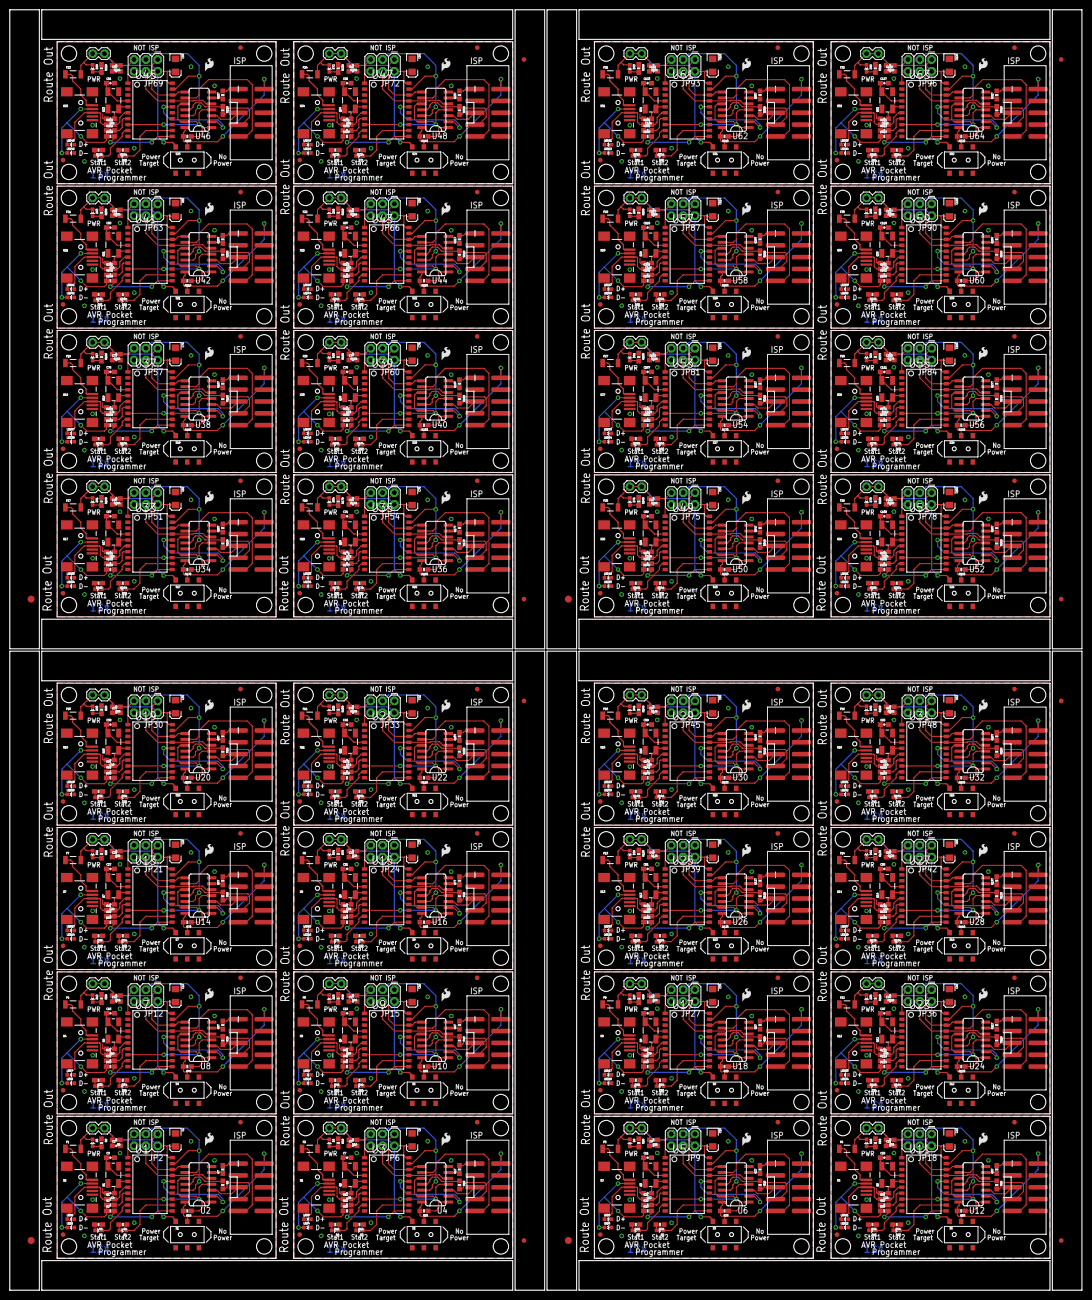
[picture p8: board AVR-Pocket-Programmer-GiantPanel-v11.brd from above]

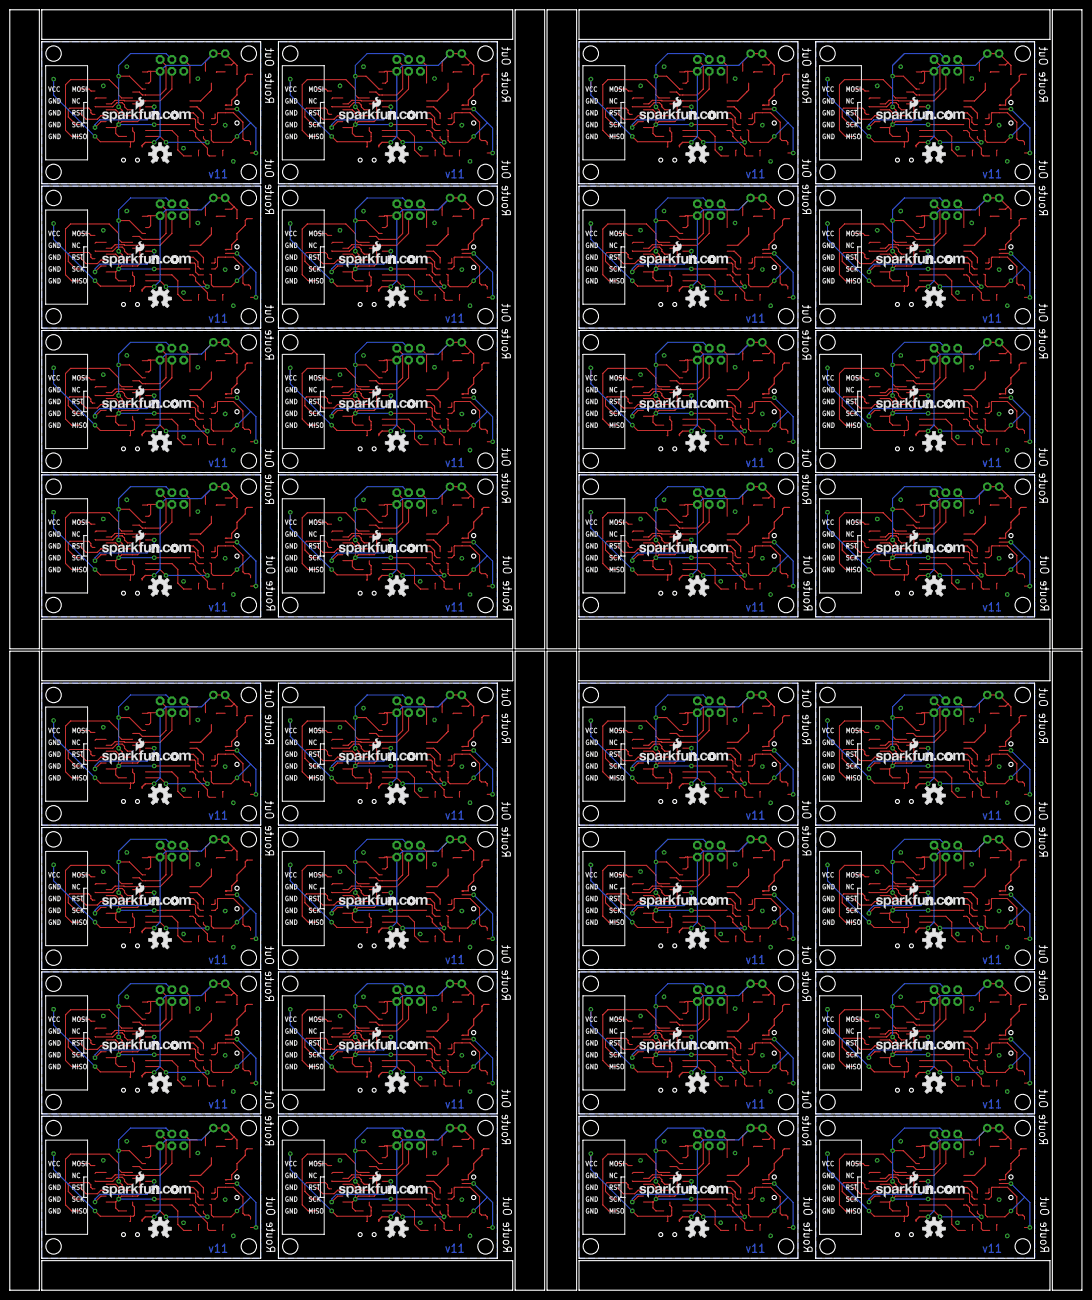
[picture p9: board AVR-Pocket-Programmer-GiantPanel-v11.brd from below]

Board: 2 copper layers, 230.1 x 274.8 mm, 1196 parts (64 on the bottom side), 896 nets.

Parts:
C1, C6, C10, C14, C18, C22, C26, C30, C34, C38, C42, C46, C50, C54, C58, C62, C66, C70, C74, C78, C82, C86, C90, C94, C98, C102, C106, C110, C114, C118, C122, C126: 10uF; EIA3216
C2, C5, C9, C13, C17, C21, C25, C29, C33, C37, C41, C45, C49, C53, C57, C61, C65, C69, C73, C77, C81, C85, C89, C93, C97, C101, C105, C109, C113, C117, C121, C125: 0.1uF; 0603-CAP
C3, C4, C7, C8, C11, C12, C15, C16, C19, C20, C23, C24, C27, C28, C31, C32, C35, C36, C39, C40, C43, C44, C47, C48, C51, C52, C55, C56, C59, C60, C63, C64, C67, C68, C71, C72, C75, C76, C79, C80, C83, C84, C87, C88, C91, C92, C95, C96, C99, C100, C103, C104, C107, C108, C111, C112, C115, C116, C119, C120, C123, C124, C127, C128: 22pF; 0603-CAP
D1, D3, D5, D6, D8, D9, D11, D12, D14, D15, D17, D18, D20, D21, D23, D24, D26, D27, D29, D30, D32, D33, D35, D36, D38, D39, D41, D42, D44, D45, D47, D48, D50, D51, D53, D54, D56, D57, D59, D60, D62, D63, D65, D66, D68, D69, D71, D72, D74, D75, D77, D78, D80, D81, D83, D84, D86, D87, D89, D90, D92, D93, D95, D96: Blue; LED-0603
D2, D4, D7, D10, D13, D16, D19, D22, D25, D28, D31, D34, D37, D40, D43, D46, D49, D52, D55, D58, D61, D64, D67, D70, D73, D76, D79, D82, D85, D88, D91, D94: Red; LED-0603
E$1, E$4, E$9, E$12: FIDUCIAL-1.5X3
E$2, E$3, E$5, E$6, E$7, E$8, E$10, E$11: FIDUCIAL-1X2
F1, F2, F3, F4, F5, F6, F7, F8, F9, F10, F11, F12, F13, F14, F15, F16, F17, F18, F19, F20, F21, F22, F23, F24, F25, F26, F27, F28, F29, F30, F31, F32: 500mA; PTC-1206-WIDE
JP1, JP4, JP7, JP10, JP13, JP16, JP19, JP22, JP25, JP28, JP31, JP34, JP37, JP40, JP43, JP46, JP49, JP52, JP55, JP58, JP61, JP64, JP67, JP70, JP73, JP76, JP79, JP82, JP85, JP88, JP91, JP94: Power Select; 1X02
JP2, JP6, JP9, JP12, JP15, JP18, JP21, JP24, JP27, JP30, JP33, JP36, JP39, JP42, JP45, JP48, JP51, JP54, JP57, JP60, JP63, JP66, JP69, JP72, JP75, JP78, JP81, JP84, JP87, JP90, JP93, JP96: AVR_SPI_PRG_6PTH; 2X3
JP3, JP5, JP8, JP11, JP14, JP17, JP20, JP23, JP26, JP29, JP32, JP35, JP38, JP41, JP44, JP47, JP50, JP53, JP56, JP59, JP62, JP65, JP68, JP71, JP74, JP77, JP80, JP83, JP86, JP89, JP92, JP95: AVR_SPI_PROG2SHROUDED_SMD; 2X5-SHROUDED_SMD
LED1, LED2, LED3, LED4, LED5, LED6, LED7, LED8, LED9, LED10, LED11, LED12, LED13, LED14, LED15, LED16, LED17, LED18, LED19, LED20, LED21, LED22, LED23, LED24, LED25, LED26, LED27, LED28, LED29, LED30, LED31, LED32, LED33, LED34, LED35, LED36, LED37, LED38, LED39, LED40, LED41, LED42, LED43, LED44, LED45, LED46, LED47, LED48, LED49, LED50, LED51, LED52, LED53, LED54, LED55, LED56, LED57, LED58, LED59, LED60, LED61, LED62, LED63, LED64: Blue; LED-0603
LOGO1, LOGO2, LOGO3, LOGO4, LOGO5, LOGO6, LOGO7, LOGO8, LOGO9, LOGO10, LOGO11, LOGO12, LOGO13, LOGO14, LOGO15, LOGO16, LOGO17, LOGO18, LOGO19, LOGO20, LOGO21, LOGO22, LOGO23, LOGO24, LOGO25, LOGO26, LOGO27, LOGO28, LOGO29, LOGO30, LOGO31, LOGO32: OSHW-LOGOM; OSHW-LOGO-M
Q1, Q2, Q3, Q4, Q5, Q6, Q7, Q8, Q9, Q10, Q11, Q12, Q13, Q14, Q15, Q16, Q17, Q18, Q19, Q20, Q21, Q22, Q23, Q24, Q25, Q26, Q27, Q28, Q29, Q30, Q31, Q32: 12 MHz; CRYSTAL-SMD-5X3
R1, R2, R11, R12, R21, R22, R31, R32, R41, R42, R51, R52, R61, R62, R71, R72, R81, R82, R91, R92, R101, R102, R111, R112, R121, R122, R131, R132, R141, R142, R151, R152, R161, R162, R171, R172, R181, R182, R191, R192, R201, R202, R211, R212, R221, R222, R231, R232, R241, R242, R251, R252, R261, R262, R271, R272, R281, R282, R291, R292, R301, R302, R311, R312: 27; 0603-RES
R3, R13, R23, R33, R43, R53, R63, R73, R83, R93, R103, R113, R123, R133, R143, R153, R163, R173, R183, R193, R203, R213, R223, R233, R243, R253, R263, R273, R283, R293, R303, R313: 1.5K; 0603-RES
R4, R5, R6, R9, R14, R15, R16, R19, R24, R25, R26, R29, R34, R35, R36, R39, R44, R45, R46, R49, R54, R55, R56, R59, R64, R65, R66, R69, R74, R75, R76, R79, R84, R85, R86, R89, R94, R95, R96, R99, R104, R105, R106, R109, R114, R115, R116, R119, R124, R125, R126, R129, R134, R135, R136, R139, R144, R145, R146, R149, R154, R155, R156, R159, R164, R165, R166, R169, R174, R175, R176, R179, R184, R185, R186, R189, R194, R195, R196, R199, R204, R205, R206, R209, R214, R215, R216, R219, R224, R225, R226, R229, R234, R235, R236, R239, R244, R245, R246, R249, R254, R255, R256, R259, R264, R265, R266, R269, R274, R275, R276, R279, R284, R285, R286, R289, R294, R295, R296, R299, R304, R305, R306, R309, R314, R315, R316, R319: 1K; 0603-RES
R7, R8, R17, R18, R27, R28, R37, R38, R47, R48, R57, R58, R67, R68, R77, R78, R87, R88, R97, R98, R107, R108, R117, R118, R127, R128, R137, R138, R147, R148, R157, R158, R167, R168, R177, R178, R187, R188, R197, R198, R207, R208, R217, R218, R227, R228, R237, R238, R247, R248, R257, R258, R267, R268, R277, R278, R287, R288, R297, R298, R307, R308, R317, R318: 100; 0603-RES
R10, R20, R30, R40, R50, R60, R70, R80, R90, R100, R110, R120, R130, R140, R150, R160, R170, R180, R190, R200, R210, R220, R230, R240, R250, R260, R270, R280, R290, R300, R310, R320: 22K; 0603-RES
S1, S2, S3, S4, S5, S6, S7, S8, S9, S10, S11, S12, S13, S14, S15, S16, S17, S18, S19, S20, S21, S22, S23, S24, S25, S26, S27, S28, S29, S30, S31, S32: Power Select; AYZ0202
U1, U3, U5, U7, U9, U11, U13, U15, U17, U19, U21, U23, U25, U27, U29, U31, U33, U35, U37, U39, U41, U43, U45, U47, U49, U51, U53, U55, U57, U59, U61, U63: ATTINY2313-20S; SO20L
U2, U4, U6, U8, U10, U12, U14, U16, U18, U20, U22, U24, U26, U28, U30, U32, U34, U36, U38, U40, U42, U44, U46, U48, U50, U52, U54, U56, U58, U60, U62, U64: 74ACT125D; SO014
U$1, U$3, U$4, U$5, U$9, U$10, U$11, U$12, U$17, U$18, U$19, U$20, U$25, U$26, U$27, U$28, U$33, U$34, U$35, U$36, U$41, U$42, U$43, U$44, U$49, U$50, U$51, U$52, U$57, U$58, U$59, U$60, U$65, U$66, U$67, U$68, U$73, U$74, U$75, U$76, U$81, U$82, U$83, U$84, U$89, U$90, U$91, U$92, U$97, U$98, U$99, U$100, U$105, U$106, U$107, U$108, U$113, U$114, U$115, U$116, U$121, U$122, U$123, U$124, U$129, U$130, U$131, U$132, U$137, U$138, U$139, U$140, U$145, U$146, U$147, U$148, U$153, U$154, U$155, U$156, U$161, U$162, U$163, U$164, U$169, U$170, U$171, U$172, U$177, U$178, U$179, U$180, U$185, U$186, U$187, U$188, U$193, U$194, U$195, U$196, U$201, U$202, U$203, U$204, U$209, U$210, U$211, U$212, U$217, U$218, U$219, U$220, U$225, U$226, U$227, U$228, U$233, U$234, U$235, U$236, U$241, U$242, U$243, U$244, U$249, U$250, U$251, U$252: STAND-OFF
U$2, U$16, U$24, U$32, U$40, U$48, U$56, U$64, U$72, U$80, U$88, U$96, U$104, U$112, U$120, U$128, U$136, U$144, U$152, U$160, U$168, U$176, U$184, U$192, U$200, U$208, U$216, U$224, U$232, U$240, U$248, U$256: LOGO-SFESK; SFE-LOGO-FLAME
U$6, U$7, U$13, U$14, U$21, U$22, U$29, U$30, U$37, U$38, U$45, U$46, U$53, U$54, U$61, U$62, U$69, U$70, U$77, U$78, U$85, U$86, U$93, U$94, U$101, U$102, U$109, U$110, U$117, U$118, U$125, U$126, U$133, U$134, U$141, U$142, U$149, U$150, U$157, U$158, U$165, U$166, U$173, U$174, U$181, U$182, U$189, U$190, U$197, U$198, U$205, U$206, U$213, U$214, U$221, U$222, U$229, U$230, U$237, U$238, U$245, U$246, U$253, U$254: FIDUCIAL1X2; FIDUCIAL-1X2
U$8, U$15, U$23, U$31, U$39, U$47, U$55, U$63, U$71, U$79, U$87, U$95, U$103, U$111, U$119, U$127, U$135, U$143, U$151, U$159, U$167, U$175, U$183, U$191, U$199, U$207, U$215, U$223, U$231, U$239, U$247, U$255: LOGO-SFENEW; SFE-NEW-WEBLOGO
X1, X2, X3, X4, X5, X6, X7, X8, X9, X10, X11, X12, X13, X14, X15, X16, X17, X18, X19, X20, X21, X22, X23, X24, X25, X26, X27, X28, X29, X30, X31, X32: USBSMD; USB-MINIB

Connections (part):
CTL: R10.1, U1.8, U2.1, U2.4, U2.10, U2.13
CTL1: R20.1, U3.8, U4.1, U4.4, U4.10, U4.13
CTL2: R30.1, U5.8, U6.1, U6.4, U6.10, U6.13
CTL3: R40.1, U7.8, U8.1, U8.4, U8.10, U8.13
CTL4: R50.1, U9.8, U10.1, U10.4, U10.10, U10.13
CTL5: R60.1, U11.8, U12.1, U12.4, U12.10, U12.13
CTL6: R70.1, U13.8, U14.1, U14.4, U14.10, U14.13
CTL7: R80.1, U15.8, U16.1, U16.4, U16.10, U16.13
CTL8: R90.1, U17.8, U18.1, U18.4, U18.10, U18.13
CTL9: R100.1, U19.8, U20.1, U20.4, U20.10, U20.13
CTL10: R110.1, U21.8, U22.1, U22.4, U22.10, U22.13
CTL11: R120.1, U23.8, U24.1, U24.4, U24.10, U24.13
CTL12: R130.1, U25.8, U26.1, U26.4, U26.10, U26.13
CTL13: R140.1, U27.8, U28.1, U28.4, U28.10, U28.13
CTL14: R150.1, U29.8, U30.1, U30.4, U30.10, U30.13
CTL15: R160.1, U31.8, U32.1, U32.4, U32.10, U32.13
CTL16: R170.1, U33.8, U34.1, U34.4, U34.10, U34.13
CTL17: R180.1, U35.8, U36.1, U36.4, U36.10, U36.13
CTL18: R190.1, U37.8, U38.1, U38.4, U38.10, U38.13
CTL19: R200.1, U39.8, U40.1, U40.4, U40.10, U40.13
CTL20: R210.1, U41.8, U42.1, U42.4, U42.10, U42.13
CTL21: R220.1, U43.8, U44.1, U44.4, U44.10, U44.13
CTL22: R230.1, U45.8, U46.1, U46.4, U46.10, U46.13
CTL23: R240.1, U47.8, U48.1, U48.4, U48.10, U48.13
CTL24: R250.1, U49.8, U50.1, U50.4, U50.10, U50.13
CTL25: R260.1, U51.8, U52.1, U52.4, U52.10, U52.13
CTL26: R270.1, U53.8, U54.1, U54.4, U54.10, U54.13
CTL27: R280.1, U55.8, U56.1, U56.4, U56.10, U56.13
CTL28: R290.1, U57.8, U58.1, U58.4, U58.10, U58.13
CTL29: R300.1, U59.8, U60.1, U60.4, U60.10, U60.13
CTL30: R310.1, U61.8, U62.1, U62.4, U62.10, U62.13
CTL31: R320.1, U63.8, U64.1, U64.4, U64.10, U64.13
D+: LED1.A, R1.1, X2.D+
D+1: LED3.A, R11.1, X1.D+
D+2: LED5.A, R21.1, X3.D+
D+3: LED7.A, R31.1, X4.D+
D+4: LED9.A, R41.1, X5.D+
D+5: LED11.A, R51.1, X6.D+
D+6: LED13.A, R61.1, X7.D+
D+7: LED15.A, R71.1, X8.D+
D+8: LED17.A, R81.1, X9.D+
D+9: LED19.A, R91.1, X10.D+
D+10: LED21.A, R101.1, X11.D+
D+11: LED23.A, R111.1, X12.D+
D+12: LED25.A, R121.1, X13.D+
D+13: LED27.A, R131.1, X14.D+
D+14: LED29.A, R141.1, X15.D+
D+15: LED31.A, R151.1, X16.D+
D+16: LED33.A, R161.1, X17.D+
D+17: LED35.A, R171.1, X18.D+
D+18: LED37.A, R181.1, X19.D+
D+19: LED39.A, R191.1, X20.D+
D+20: LED41.A, R201.1, X21.D+
D+21: LED43.A, R211.1, X22.D+
D+22: LED45.A, R221.1, X23.D+
D+23: LED47.A, R231.1, X24.D+
D+24: LED49.A, R241.1, X25.D+
D+25: LED51.A, R251.1, X26.D+
D+26: LED53.A, R261.1, X27.D+
D+27: LED55.A, R271.1, X28.D+
D+28: LED57.A, R281.1, X29.D+
D+29: LED59.A, R291.1, X30.D+
D+30: LED61.A, R301.1, X31.D+
D+31: LED63.A, R311.1, X32.D+
D-: LED2.A, R2.1, R3.1, X2.D-
D-1: LED4.A, R12.1, R13.1, X1.D-
D-2: LED6.A, R22.1, R23.1, X3.D-
D-3: LED8.A, R32.1, R33.1, X4.D-
D-4: LED10.A, R42.1, R43.1, X5.D-
D-5: LED12.A, R52.1, R53.1, X6.D-
D-6: LED14.A, R62.1, R63.1, X7.D-
D-7: LED16.A, R72.1, R73.1, X8.D-
D-8: LED18.A, R82.1, R83.1, X9.D-
D-9: LED20.A, R92.1, R93.1, X10.D-
D-10: LED22.A, R102.1, R103.1, X11.D-
D-11: LED24.A, R112.1, R113.1, X12.D-
D-12: LED26.A, R122.1, R123.1, X13.D-
D-13: LED28.A, R132.1, R133.1, X14.D-
D-14: LED30.A, R142.1, R143.1, X15.D-
D-15: LED32.A, R152.1, R153.1, X16.D-
D-16: LED34.A, R162.1, R163.1, X17.D-
D-17: LED36.A, R172.1, R173.1, X18.D-
D-18: LED38.A, R182.1, R183.1, X19.D-
D-19: LED40.A, R192.1, R193.1, X20.D-
D-20: LED42.A, R202.1, R203.1, X21.D-
D-21: LED44.A, R212.1, R213.1, X22.D-
D-22: LED46.A, R222.1, R223.1, X23.D-
D-23: LED48.A, R232.1, R233.1, X24.D-
D-24: LED50.A, R242.1, R243.1, X25.D-
D-25: LED52.A, R252.1, R253.1, X26.D-
D-26: LED54.A, R262.1, R263.1, X27.D-
D-27: LED56.A, R272.1, R273.1, X28.D-
D-28: LED58.A, R282.1, R283.1, X29.D-
D-29: LED60.A, R292.1, R293.1, X30.D-
D-30: LED62.A, R302.1, R303.1, X31.D-
D-31: LED64.A, R312.1, R313.1, X32.D-
GND: C1.C, C2.2, C3.2, C4.2, JP2.6, JP3.4, JP3.6, JP3.8, JP3.10, LED1.C, LED2.C, R4.1, R5.1, R9.1, U1.10, U2.7, X2.GND
GND1: C5.2, C6.C, C7.2, C8.2, JP5.4, JP5.6, JP5.8, JP5.10, JP6.6, LED3.C, LED4.C, R14.1, R15.1, R19.1, U3.10, U4.7, X1.GND
GND2: C9.2, C10.C, C11.2, C12.2, JP8.4, JP8.6, JP8.8, JP8.10, JP9.6, LED5.C, LED6.C, R24.1, R25.1, R29.1, U5.10, U6.7, X3.GND
GND3: C13.2, C14.C, C15.2, C16.2, JP11.4, JP11.6, JP11.8, JP11.10, JP12.6, LED7.C, LED8.C, R34.1, R35.1, R39.1, U7.10, U8.7, X4.GND
GND4: C17.2, C18.C, C19.2, C20.2, JP14.4, JP14.6, JP14.8, JP14.10, JP15.6, LED9.C, LED10.C, R44.1, R45.1, R49.1, U9.10, U10.7, X5.GND
GND5: C21.2, C22.C, C23.2, C24.2, JP17.4, JP17.6, JP17.8, JP17.10, JP18.6, LED11.C, LED12.C, R54.1, R55.1, R59.1, U11.10, U12.7, X6.GND
GND6: C25.2, C26.C, C27.2, C28.2, JP20.4, JP20.6, JP20.8, JP20.10, JP21.6, LED13.C, LED14.C, R64.1, R65.1, R69.1, U13.10, U14.7, X7.GND
GND7: C29.2, C30.C, C31.2, C32.2, JP23.4, JP23.6, JP23.8, JP23.10, JP24.6, LED15.C, LED16.C, R74.1, R75.1, R79.1, U15.10, U16.7, X8.GND
GND8: C33.2, C34.C, C35.2, C36.2, JP26.4, JP26.6, JP26.8, JP26.10, JP27.6, LED17.C, LED18.C, R84.1, R85.1, R89.1, U17.10, U18.7, X9.GND
GND9: C37.2, C38.C, C39.2, C40.2, JP29.4, JP29.6, JP29.8, JP29.10, JP30.6, LED19.C, LED20.C, R94.1, R95.1, R99.1, U19.10, U20.7, X10.GND
GND10: C41.2, C42.C, C43.2, C44.2, JP32.4, JP32.6, JP32.8, JP32.10, JP33.6, LED21.C, LED22.C, R104.1, R105.1, R109.1, U21.10, U22.7, X11.GND
GND11: C45.2, C46.C, C47.2, C48.2, JP35.4, JP35.6, JP35.8, JP35.10, JP36.6, LED23.C, LED24.C, R114.1, R115.1, R119.1, U23.10, U24.7, X12.GND
GND12: C49.2, C50.C, C51.2, C52.2, JP38.4, JP38.6, JP38.8, JP38.10, JP39.6, LED25.C, LED26.C, R124.1, R125.1, R129.1, U25.10, U26.7, X13.GND
GND13: C53.2, C54.C, C55.2, C56.2, JP41.4, JP41.6, JP41.8, JP41.10, JP42.6, LED27.C, LED28.C, R134.1, R135.1, R139.1, U27.10, U28.7, X14.GND
GND14: C57.2, C58.C, C59.2, C60.2, JP44.4, JP44.6, JP44.8, JP44.10, JP45.6, LED29.C, LED30.C, R144.1, R145.1, R149.1, U29.10, U30.7, X15.GND
GND15: C61.2, C62.C, C63.2, C64.2, JP47.4, JP47.6, JP47.8, JP47.10, JP48.6, LED31.C, LED32.C, R154.1, R155.1, R159.1, U31.10, U32.7, X16.GND
GND16: C65.2, C66.C, C67.2, C68.2, JP50.4, JP50.6, JP50.8, JP50.10, JP51.6, LED33.C, LED34.C, R164.1, R165.1, R169.1, U33.10, U34.7, X17.GND
GND17: C69.2, C70.C, C71.2, C72.2, JP53.4, JP53.6, JP53.8, JP53.10, JP54.6, LED35.C, LED36.C, R174.1, R175.1, R179.1, U35.10, U36.7, X18.GND
GND18: C73.2, C74.C, C75.2, C76.2, JP56.4, JP56.6, JP56.8, JP56.10, JP57.6, LED37.C, LED38.C, R184.1, R185.1, R189.1, U37.10, U38.7, X19.GND
GND19: C77.2, C78.C, C79.2, C80.2, JP59.4, JP59.6, JP59.8, JP59.10, JP60.6, LED39.C, LED40.C, R194.1, R195.1, R199.1, U39.10, U40.7, X20.GND
GND20: C81.2, C82.C, C83.2, C84.2, JP62.4, JP62.6, JP62.8, JP62.10, JP63.6, LED41.C, LED42.C, R204.1, R205.1, R209.1, U41.10, U42.7, X21.GND
GND21: C85.2, C86.C, C87.2, C88.2, JP65.4, JP65.6, JP65.8, JP65.10, JP66.6, LED43.C, LED44.C, R214.1, R215.1, R219.1, U43.10, U44.7, X22.GND
GND22: C89.2, C90.C, C91.2, C92.2, JP68.4, JP68.6, JP68.8, JP68.10, JP69.6, LED45.C, LED46.C, R224.1, R225.1, R229.1, U45.10, U46.7, X23.GND
GND23: C93.2, C94.C, C95.2, C96.2, JP71.4, JP71.6, JP71.8, JP71.10, JP72.6, LED47.C, LED48.C, R234.1, R235.1, R239.1, U47.10, U48.7, X24.GND
GND24: C97.2, C98.C, C99.2, C100.2, JP74.4, JP74.6, JP74.8, JP74.10, JP75.6, LED49.C, LED50.C, R244.1, R245.1, R249.1, U49.10, U50.7, X25.GND
GND25: C101.2, C102.C, C103.2, C104.2, JP77.4, JP77.6, JP77.8, JP77.10, JP78.6, LED51.C, LED52.C, R254.1, R255.1, R259.1, U51.10, U52.7, X26.GND
GND26: C105.2, C106.C, C107.2, C108.2, JP80.4, JP80.6, JP80.8, JP80.10, JP81.6, LED53.C, LED54.C, R264.1, R265.1, R269.1, U53.10, U54.7, X27.GND
GND27: C109.2, C110.C, C111.2, C112.2, JP83.4, JP83.6, JP83.8, JP83.10, JP84.6, LED55.C, LED56.C, R274.1, R275.1, R279.1, U55.10, U56.7, X28.GND
GND28: C113.2, C114.C, C115.2, C116.2, JP86.4, JP86.6, JP86.8, JP86.10, JP87.6, LED57.C, LED58.C, R284.1, R285.1, R289.1, U57.10, U58.7, X29.GND
GND29: C117.2, C118.C, C119.2, C120.2, JP89.4, JP89.6, JP89.8, JP89.10, JP90.6, LED59.C, LED60.C, R294.1, R295.1, R299.1, U59.10, U60.7, X30.GND
GND30: C121.2, C122.C, C123.2, C124.2, JP92.4, JP92.6, JP92.8, JP92.10, JP93.6, LED61.C, LED62.C, R304.1, R305.1, R309.1, U61.10, U62.7, X31.GND
GND31: C125.2, C126.C, C127.2, C128.2, JP95.4, JP95.6, JP95.8, JP95.10, JP96.6, LED63.C, LED64.C, R314.1, R315.1, R319.1, U63.10, U64.7, X32.GND
MISO': JP2.1, U1.18, U2.8
MISO'1: JP6.1, U3.18, U4.8
MISO'2: JP9.1, U5.18, U6.8
MISO'3: JP12.1, U7.18, U8.8
MISO'4: JP15.1, U9.18, U10.8
MISO'5: JP18.1, U11.18, U12.8
MISO'6: JP21.1, U13.18, U14.8
MISO'7: JP24.1, U15.18, U16.8
MISO'8: JP27.1, U17.18, U18.8
MISO'9: JP30.1, U19.18, U20.8
MISO'10: JP33.1, U21.18, U22.8
MISO'11: JP36.1, U23.18, U24.8
MISO'12: JP39.1, U25.18, U26.8
MISO'13: JP42.1, U27.18, U28.8
MISO'14: JP45.1, U29.18, U30.8
MISO'15: JP48.1, U31.18, U32.8
MISO'16: JP51.1, U33.18, U34.8
MISO'17: JP54.1, U35.18, U36.8
MISO'18: JP57.1, U37.18, U38.8
MISO'19: JP60.1, U39.18, U40.8
MISO'20: JP63.1, U41.18, U42.8
MISO'21: JP66.1, U43.18, U44.8
MISO'22: JP69.1, U45.18, U46.8
MISO'23: JP72.1, U47.18, U48.8
MISO'24: JP75.1, U49.18, U50.8
MISO'25: JP78.1, U51.18, U52.8
MISO'26: JP81.1, U53.18, U54.8
MISO'27: JP84.1, U55.18, U56.8
MISO'28: JP87.1, U57.18, U58.8
MISO'29: JP90.1, U59.18, U60.8
MISO'30: JP93.1, U61.18, U62.8
MISO'31: JP96.1, U63.18, U64.8
MOSI': JP2.4, U1.17, U2.5
MOSI'1: JP6.4, U3.17, U4.5
MOSI'2: JP9.4, U5.17, U6.5
MOSI'3: JP12.4, U7.17, U8.5
MOSI'4: JP15.4, U9.17, U10.5
MOSI'5: JP18.4, U11.17, U12.5
MOSI'6: JP21.4, U13.17, U14.5
MOSI'7: JP24.4, U15.17, U16.5
MOSI'8: JP27.4, U17.17, U18.5
MOSI'9: JP30.4, U19.17, U20.5
MOSI'10: JP33.4, U21.17, U22.5
MOSI'11: JP36.4, U23.17, U24.5
MOSI'12: JP39.4, U25.17, U26.5
MOSI'13: JP42.4, U27.17, U28.5
MOSI'14: JP45.4, U29.17, U30.5
MOSI'15: JP48.4, U31.17, U32.5
MOSI'16: JP51.4, U33.17, U34.5
MOSI'17: JP54.4, U35.17, U36.5
MOSI'18: JP57.4, U37.17, U38.5
MOSI'19: JP60.4, U39.17, U40.5
MOSI'20: JP63.4, U41.17, U42.5
MOSI'21: JP66.4, U43.17, U44.5
MOSI'22: JP69.4, U45.17, U46.5
MOSI'23: JP72.4, U47.17, U48.5
MOSI'24: JP75.4, U49.17, U50.5
MOSI'25: JP78.4, U51.17, U52.5
MOSI'26: JP81.4, U53.17, U54.5
MOSI'27: JP84.4, U55.17, U56.5
MOSI'28: JP87.4, U57.17, U58.5
MOSI'29: JP90.4, U59.17, U60.5
MOSI'30: JP93.4, U61.17, U62.5
MOSI'31: JP96.4, U63.17, U64.5
unnamed: R3.2, U1.11
unnamed: D2.A, U1.9
unnamed: D3.C, R9.2
unnamed: F1.1, X2.VBUS
unnamed: C3.1, Q1.3, U1.4
unnamed: C4.1, Q1.1, U1.5
unnamed: R13.2, U3.11
unnamed: D4.A, U3.9
unnamed: D5.A, U3.12
unnamed: D5.C, R14.2
unnamed: D4.C, R15.2
unnamed: R17.1, U4.6
unnamed: R18.1, U4.11
unnamed: D6.C, R19.2
unnamed: F2.1, X1.VBUS
unnamed: C7.1, Q2.3, U3.4
unnamed: D1.A, U1.12
unnamed: D1.C, R4.2
unnamed: D2.C, R5.2
unnamed: C8.1, Q2.1, U3.5
unnamed: R23.2, U5.11
unnamed: R7.1, U2.6
unnamed: D7.A, U5.9
unnamed: D8.A, U5.12
unnamed: R8.1, U2.11
unnamed: D8.C, R24.2
unnamed: D7.C, R25.2
unnamed: R27.1, U6.6
unnamed: R28.1, U6.11
unnamed: D9.C, R29.2
unnamed: F3.1, X3.VBUS
unnamed: C11.1, Q3.3, U5.4
unnamed: C12.1, Q3.1, U5.5
unnamed: R33.2, U7.11
unnamed: D10.A, U7.9
unnamed: D11.A, U7.12
unnamed: D11.C, R34.2
unnamed: D10.C, R35.2
unnamed: R37.1, U8.6
unnamed: R38.1, U8.11
unnamed: D12.C, R39.2
unnamed: F4.1, X4.VBUS
unnamed: C15.1, Q4.3, U7.4
unnamed: C16.1, Q4.1, U7.5
unnamed: R43.2, U9.11
unnamed: D13.A, U9.9
unnamed: D14.A, U9.12
unnamed: D14.C, R44.2
unnamed: D13.C, R45.2
unnamed: R47.1, U10.6
unnamed: R48.1, U10.11
unnamed: D15.C, R49.2
unnamed: F5.1, X5.VBUS
unnamed: C19.1, Q5.3, U9.4
unnamed: C20.1, Q5.1, U9.5
unnamed: R53.2, U11.11
unnamed: D16.A, U11.9
unnamed: D17.A, U11.12
unnamed: D17.C, R54.2
unnamed: D16.C, R55.2
unnamed: R57.1, U12.6
unnamed: R58.1, U12.11
unnamed: D18.C, R59.2
unnamed: F6.1, X6.VBUS
unnamed: C23.1, Q6.3, U11.4
unnamed: C24.1, Q6.1, U11.5
unnamed: R63.2, U13.11
unnamed: D19.A, U13.9
unnamed: D20.A, U13.12
unnamed: D20.C, R64.2
unnamed: D19.C, R65.2
unnamed: R67.1, U14.6
unnamed: R68.1, U14.11
unnamed: D21.C, R69.2
unnamed: F7.1, X7.VBUS
unnamed: C27.1, Q7.3, U13.4
unnamed: C28.1, Q7.1, U13.5
unnamed: R73.2, U15.11
unnamed: D22.A, U15.9
unnamed: D23.A, U15.12
unnamed: D23.C, R74.2
unnamed: D22.C, R75.2
unnamed: R77.1, U16.6
unnamed: R78.1, U16.11
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

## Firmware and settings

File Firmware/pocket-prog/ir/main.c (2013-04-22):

// ======================================================================
// IR receiver and LCD controller with USB interface.
//
// Read IR mark/space patterns from a TSOP1738 on the ICP input pin.
// Mark and space periods are measured in units of 12Mhz/1024, which is
// 85.33 us. Up to 35 periods are stored in a buffer, where they can
// be read via a USB request. The buffer layout and USB requests are
// compatible with the "IgorPlug-USB" device, which is supported by LIRC
// through the "igorplugusb" driver. This implementation should also
// work with that driver. If IgorPlug-USB compatibility is not required,
// the resolution could be improved by reducing SCALING to 9, and you
// could also get rid of the additional endpoint (USBTINY_ENDPOINT).
//
// There are some IR protocols with very long packets length, such as
// the "NEC" protocol (http://www.xs4all.nl/~sbp/knowledge/ir/nec.htm).
// This protocol uses 67 mark/space periods, which is too much for the
// limited amount of RAM in the ATtiny2313. Simply truncating the
// packet to the amount of available buffer space is not an option,
// because the significant bits are at the end of the packet. Instead,
// a buffer of 35 bytes (IR_MAX) is used, of which the last 16 bytes
// (IR_WRAP) are used as a circular buffer. Because both the address
// (16 periods) and the command code (16 periods) are sent twice (normal
// and inverted), the wrapping will result in a buffer with both the
// device address and the inverted command code. Other IR protocols are
// typically shorter than 35 periods.
//
// 16-bit Timer1 is initialized in normal mode with a clock of 12MHz/8.
// Both the positive and negative edges of the IR input signal on the
// ICP input pin trigger an input capture interrupt, because the edge
// selection is toggled on every interrupt. Output compare register A
// is used for a timeout to detect the end of an IR transmission.
// The timeout value is updated on every edge. When at least 4 edges
// were detected when a timeout occurs, the packet count ir.count is
// incremented and the ir.length byte is set to the packed length. This
// byte is checked when a read request is received via USB to see if a
// packet is available
//
// The two interrupt handlers in this file run for more than 28 cycles,
// so they need to reenable interrupts to allow USB interrupts to be
// handled in time. To avoid nested IR interrupts, the input capture and
// output compare interrupts are disabled before the global interrupt
// flag is set. In the input capture interrupt handler, the interrupts
// are disabled for a maximum of 26, 27 and 21 cycles, and in the output
// compare interrupt handler for 21, 23 and 21 cycles. Unfortunately,
// it was not possible to meet the 28 cycle maximum for the input
// capture interrupt handler without replacing the compiler generated
// prolog and epilog code by inline assembly, which makes the code a
// little fragile.
//
// The IR receiver is disabled during an IR buffer read, so that a
// packet that is being tranmitted to the host, is not overwritten by
// the next packet. When a transfer is in progress, 'inpos' has a value
// other than 0xff. When the buffer is read completely, the IR receiver
// is reenabled again, but when the next IR packet has already started,
// this packed is discarded by setting 'edges' to 0xff.
//
// There are two USB request codes to control the LCD, one to write
// instructions, and one to write data to the display. OUT transfers
// are used to transfer up to 255 bytes for a single request.
//
// Stack space calculations for gcc-3.4.3 and gcc-4.1.0:
//
// 3.4.3   4.1.0
// -----   -----
//   0       0       main
//   0       0           lcd_init (inlined)
//   2       2           usb_init
//   0       0           ir_init (inlined)
//   6       5           usb_poll
//   0       0               usb_receive (inlined)
//   2       2                   usb_setup
//   5       5                   usb_out
//   4       4                       lcd_write
//   2       2                           lcd_read4
//   2       2                           lcd_write4
//   0       0               usb_transmit (inlined)
//   2       4                   usb_int
//   2       2                   crc
//
// Maximum stack space is 6+5+4+2=17 for gcc-3.4.3 and 5+5+4+2=16 for
// gcc-4.1.0. Total stack usage:
// - USB interrupt:			11 bytes
// - IR input capture interrupt:	11 bytes
// - IR output compare interrupt: 	 7 bytes
// - main():				17 bytes
// The two IR interrupt handler cannot be active simultaneously, so the
// maximum stack space is 17+11+11=39 bytes.
//
// NOTE: The above cycle and stack size figures were obtained by
//       inspecting the code generated by gcc-3.4.3 and gcc-4.1.0.
//       Other compiler versions may generate different code, leading
//       to different figures. Likewise, the replacement prolog and
//       epilog code may have to be adapted when a different compiler
//       version allocates different registers.
//
// Copyright (C) 2006 Dick Streefland
//
// This is free software, licensed under the terms of the GNU General
// Public License as published by the Free Software Foundation.
// ======================================================================

#include <avr/io.h>
#include <avr/interrupt.h>
#include "usb.h"

// ----------------------------------------------------------------------
// IR receiver definitions
// ----------------------------------------------------------------------

#define	TIMEOUT		10500	// IR transmission timeout in us
#define	IR_MAX		35	// maximum number of IR data bytes
#define	IR_WRAP		16	// wrap area at end (for 67 byte NEC protocol)
#define	SCALING		10	// 9: 42.67 us period, 10: 85.33 us period
#define	LED		5	// PORTD bit number for LED
#define	PULLUP		3	// PORTD bit number for D- pullup

enum
{
	// Generic requests
	USBTINY_ECHO,		// echo test
	// IgorPlug-USB requests
	IGORPLUG_CLEAR,		// clear IR data
	IGORPLUG_READ,		// read IR data (wValue: offset)
	// LCD requests
	LCD_INSTR = 20,		// write instructions to LCD (via OUT)
	LCD_DATA,		// write data to LCD (via OUT)
};

static	byte_t	inpos = 0xff;	// read position for usb_in(), or 0xff
static	byte_t	edges;		// incremented for each edge
static	struct			// IgorPlug-USB compatible data layout
{
	byte_t	length;		// length of data[]
	byte_t	count;		// incremented for each IR packet
	byte_t	offset;		// not used
	byte_t	data[IR_MAX];	// mark/space periods
}		ir;

// ----------------------------------------------------------------------
// LCD definitions
// ----------------------------------------------------------------------

#define	LCD_PRESENT	1	// set to 0 to remove LCD support

#define	DDR		DDRB
#define	PORT		PORTB
#define	PIN		PINB

#define	D4		0
#define	RS		4
#define	RW		5
#define	E		6

#define	MASK_D4		(0xf << D4)
#define	MASK_RS		(1 << RS)
#define	MASK_RW		(1 << RW)
#define	MASK_E		(1 << E)

// ----------------------------------------------------------------------
// Handler for timer1 input capture interrupt: edge on IR input
// ----------------------------------------------------------------------
__attribute__((signal,naked))			// interrupts are DISABLED
extern	void	SIG_TIMER1_CAPT ( void )
{
	static	uint_t	prev;
	uint_t		stamp;
	byte_t		delta;
	byte_t		e;

	asm volatile(
		"push	r23\n"
		"in	r23,__SREG__\n"
		"push	r18\n"
		"push	r19\n"
		"push	r24\n"
		"push	r25\n"
	:: );
	stamp = ICR1;				// get time stamp
	TIMSK = 0;				// disable both IR interrupts
	TCCR1B ^= _BV(ICES1);			// toggle edge detector
	sei();					// allow USB interrupt
	PORTD |= _BV(LED);			// switch LED on
	asm volatile(
		"push	r20\n"
		"push	r21\n"
		"push	r30\n"
		"push	r31\n"
	:: );
	delta = (stamp - prev + (1 << (SCALING-3-1))) >> (SCALING-3);
	asm volatile("" : : "r"(delta) );	// calculate delta (gcc-4.1.0)
	prev  = stamp;
	OCR1A = stamp + 12L * TIMEOUT / 8;	// update timeout value
	cli();					// enter critical region
	e = edges;
	if	( e != 0xff )			// packet should not be ignored?
	{
		if	( e > IR_MAX )		// packet too long for buffer?
		{
			e -= IR_WRAP;		// wrap, don't truncate
		}
		if	( inpos == 0xff )	// update ir only when USB idle
		{
			ir.length = 0;		// discard previous packet
			if	( e > 0 )
			{
				ir.data[e - 1] = delta;
			}
		}
		edges = e + 1;
	}
	sei();					// allow USB interrupt
	asm volatile("nop");			// reduce latency to 1 cycle
	asm volatile(
		"pop	r31\n"
		"pop	r30\n"
		"pop	r21\n"
		"pop	r20\n"
	:: );
	cli();
	TIMSK = _BV(OCIE1A) | _BV(ICIE1);	// reenable IR interrupts
	asm volatile(
		"pop	r25\n"
		"pop	r24\n"
		"pop	r19\n"
		"pop	r18\n"
		"out	__SREG__,r23\n"
		"pop	r23\n"
		"reti\n"
	:: );
}

// ----------------------------------------------------------------------
// Handler for timer1 output compare A interrupt: IR transmission timeout
// ----------------------------------------------------------------------
__attribute__((signal))				// interrupts are DISABLED
extern	void	SIG_TIMER1_COMPA ( void )
{
	TIMSK = 0;				// disable both IR interrupts
	sei();					// allow USB interrupt
	PORTD &= ~_BV(LED);			// switch LED off
	cli();					// enter critical region
	if	(  edges >= 4			// at least two pulses (NEC)
		&& edges != 0xff		// packet should not be ignored
		&& inpos == 0xff		// update ir only when USB idle
		)
	{
		ir.count++;
		ir.length = edges - 1;		// new packet is complete
	}
	edges = 0;
	sei();					// allow USB interrupt
	TCCR1B &= ~_BV(ICES1);			// reset to negative edge
	cli();
	TIMSK = _BV(OCIE1A) | _BV(ICIE1);	// reenable IR interrupts
}

// ----------------------------------------------------------------------
// Initialize the IR receiver.
// ----------------------------------------------------------------------
static	void	ir_init ( void )
{
	DDRD |= _BV(LED);
	TCCR1B = _BV(ICNC1)	// noise canceler, trigger on negative edge
	       | _BV(CS11);	// clock source clk/8
	TIMSK  = _BV(OCIE1A)	// output compare 1A match interrupt enable
	       | _BV(ICIE1);	// input capture 1 interrupt enable
}

#if	LCD_PRESENT
// ----------------------------------------------------------------------
// Delay <count> times 100 microseconds.
// ----------------------------------------------------------------------
static	void	lcd_delay100u ( byte_t count )
{
	asm volatile(
		"0:	ldi	r25, 240\n"
		"1:	rjmp	2f\n"
		"2:	dec	r25\n"
		"	brne	1b\n"	// 240 * 5 cycles = 100us
		"	dec	r24\n"
		"	brne	0b\n"
	);
}

// ----------------------------------------------------------------------
// Write 4 bits to the LCD.
// ----------------------------------------------------------------------
static	void	lcd_write4 ( byte_t data )
{
	PORT = (PORT & ~ MASK_D4) | (data << D4);
	PORT |= MASK_E;			// E high period: > 230ns
	DDR  = MASK_RS | MASK_RW | MASK_E | MASK_D4; // Dx setup time: > 80ns
	PORT &= ~ MASK_E;		// hold time: > 10ns
	DDR  = MASK_RS | MASK_RW | MASK_E;
}

// ----------------------------------------------------------------------
// Read 4 bits from the LCD.
// ----------------------------------------------------------------------
static	byte_t	lcd_read4 ( void )
{
	byte_t	save;
	byte_t	data;

	save = PORT;
	PORT = MASK_RW;			// address setup time: > 40ns
	PORT |= MASK_E;			// E high period: > 230ns
	asm volatile("rjmp 0f\n0:");
	data = (PIN & MASK_D4) >> D4;	// data access time: > 160ns
	PORT = save;
	return data;
}

// ----------------------------------------------------------------------
// Write a byte to the LCD.
// ----------------------------------------------------------------------
static	void	lcd_write ( byte_t b )
{
	byte_t	h;

	do
	{
		h = lcd_read4();
		(void) lcd_read4();
	} while	( h & 0x08 );
	lcd_write4( b >> 4 );
	lcd_write4( b & 15 );
}

// ----------------------------------------------------------------------
// Initialize the LCD.
// ----------------------------------------------------------------------
static	void	lcd_init ( void )
{
	DDR = MASK_RS | MASK_RW | MASK_E;
	PORT = 0;
	//lcd_delay100u( 150 );	-- skipped because of RESET delay
	lcd_write4( 3 );
	lcd_delay100u( 41 );
	lcd_write4( 3 );
	lcd_delay100u( 1 );
	lcd_write( 0x32 );	// switch to 4-bit mode
	lcd_write( 0x28 );	// function set: 4-bit mode, two lines
	lcd_write( 0x01 );	// clear display
	lcd_write( 0x06 );	// entry mode: increment, no shift
	lcd_write( 0x0c );	// display control: on, no cursor
}
#endif	/* LCD_PRESENT */

// ----------------------------------------------------------------------
// Handle a non-standard SETUP packet.
// ----------------------------------------------------------------------
extern	byte_t	usb_setup ( byte_t data[8] )
{
	byte_t	req;
	byte_t	r;

	r = 0;

	// Generic requests
	req = data[1];
	if	( req == USBTINY_ECHO )
	{
		r = 8;
	}

	// IgorPlug-USB requests
	if	( req == IGORPLUG_CLEAR )
	{
		ir.length = 0;
		inpos = 0xff;
	}
	if	( req == IGORPLUG_READ )
	{
		cli();
		if	( ir.length > 0 )
		{
			inpos = data[4];
			r = 0xff;	// call usb_in() to get the data
		}
		else
		{
			data[0] = 0;
			r = 1;
		}
		sei();
	}

	// LCD requests
	if	( req == LCD_INSTR )
	{
		PORT &= ~ MASK_RS;	// data will be received by usb_out()
	}
	if	( req == LCD_DATA )
	{
		PORT |= MASK_RS;	// data will be received by usb_out()
	}

	return r;
}

// ----------------------------------------------------------------------
// Handle an IN packet.
// ----------------------------------------------------------------------
extern	byte_t	usb_in ( byte_t* data, byte_t len )
{
	byte_t	n;
	byte_t	max;

	max = ir.length + 3;
	n = 0;
	while	( n < len )
	{
		if	( inpos >= max )	// end of packet?
		{
			cli();
			if	( edges )	// next packet already started?
			{
				edges = 0xff;	// ignore remainder of packet
			}
			inpos = 0xff;		// reenable receiver
			sei();
			break;
		}
		data[n++] = (& ir.length)[inpos++];
	}
	return n;
}

// ----------------------------------------------------------------------
// Handle an OUT packet.
// ----------------------------------------------------------------------
extern	void	usb_out ( byte_t* data, byte_t len )
{
#if	LCD_PRESENT
	while	( len )
	{
		lcd_write( *data++ );
		len--;
	}
#endif	/* LCD_PRESENT */
}

// ----------------------------------------------------------------------
// Main
// ----------------------------------------------------------------------
__attribute__((naked))		// suppress redundant SP initialization
extern	int	main ( void )
{
	PORTD |= _BV(PULLUP);
	DDRD  |= _BV(PULLUP);	// enable pullup on D-
#if	LCD_PRESENT
	lcd_init();
#endif	/* LCD_PRESENT */
	usb_init();
	ir_init();
	for	( ;; )
	{
		usb_poll();
	}
	return 0;
}

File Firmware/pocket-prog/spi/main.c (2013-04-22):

// ======================================================================
// Control a parallel port AVR programmer (avrdude type "bsd") via USB.
//
// Copyright (C) 2006 Dick Streefland
//
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
// ======================================================================

#include <avr/io.h>
#include "usb.h"

enum
{
	// Generic requests
	USBTINY_ECHO,		// echo test
	USBTINY_READ,		// read byte
	USBTINY_WRITE,		// write byte
	USBTINY_CLR,		// clear bit 
	USBTINY_SET,		// set bit
	// Programming requests
	USBTINY_POWERUP,	// apply power (wValue:SCK-period, wIndex:RESET)
	USBTINY_POWERDOWN,	// remove power from chip
	USBTINY_SPI,		// issue SPI command (wValue:c1c0, wIndex:c3c2)
	USBTINY_POLL_BYTES,	// set poll bytes for write (wValue:p1p2)
	USBTINY_FLASH_READ,	// read flash (wIndex:address)
	USBTINY_FLASH_WRITE,	// write flash (wIndex:address, wValue:timeout)
	USBTINY_EEPROM_READ,	// read eeprom (wIndex:address)
	USBTINY_EEPROM_WRITE,	// write eeprom (wIndex:address, wValue:timeout)
	USBTINY_DDRWRITE,        // set port direction
	USBTINY_SPI1            // a single SPI command
};

// ----------------------------------------------------------------------
// Programmer output pins:
//	LED	PB0	(D0)
#define LED PB0
//	VCC	PB1	(D1)
//	VCC	PB2	(D2)
//	VCC	PB3	(D3)
//	RESET	PB5	(D4)
#define RESET PB4
//	MOSI	PB5	(D5)
#define MOSI  PB5
//	SCK	PB7	(D7)
#define SCK   PB7

// ----------------------------------------------------------------------
#define	PORT		PORTB
#define	DDR		DDRB
#define	POWER_MASK	_BV(LED)
#define	RESET_MASK	_BV(RESET)
#define	SCK_MASK	_BV(SCK)
#define	MOSI_MASK	_BV(MOSI)
#define LED_MASK        _BV(LED)

// ----------------------------------------------------------------------
// Programmer input pins:
//	MISO	PB6
#define MISO       6
// ----------------------------------------------------------------------
#define	PIN		PINB
#define	MISO_MASK	_BV(MISO)

// ----------------------------------------------------------------------
// Local data
// ----------------------------------------------------------------------
static	byte_t		sck_period;	// SCK period in microseconds (1..250)
static	byte_t		poll1;		// first poll byte for write
static	byte_t		poll2;		// second poll byte for write
static	uint_t		address;	// read/write address
static	uint_t		timeout;	// write timeout in usec
static	byte_t		cmd0;		// current read/write command byte
static	byte_t		cmd[4];		// SPI command buffer
static	byte_t		res[4];		// SPI result buffer

// ----------------------------------------------------------------------
// Delay exactly <sck_period> times 0.5 microseconds (6 cycles).
// ----------------------------------------------------------------------
__attribute__((always_inline))
static	void	delay ( void )
{
	asm volatile(
		"	mov	__tmp_reg__,%0	\n"
		"0:	rjmp	1f		\n"
		"1:	nop			\n"
		"	dec	__tmp_reg__	\n"
		"	brne	0b		\n"
		: : "r" (sck_period) );
}

// ----------------------------------------------------------------------
// Issue one SPI command.
// ----------------------------------------------------------------------
static	void	spi ( byte_t* cmd, byte_t* res, int i )
{
	byte_t	c;
	byte_t	r;
	byte_t	mask;

	while (i != 0)
	{
	  i--;
		c = *cmd++;
		r = 0;
		for	( mask = 0x80; mask; mask >>= 1 )
		{
			if	( c & mask )
			{
				PORT |= MOSI_MASK;
			}
			delay();
			PORT |= SCK_MASK;
			delay();
			r <<= 1;
			if	( PIN & MISO_MASK )
			{
				r++;
			}
			PORT &= ~ MOSI_MASK;
			PORT &= ~ SCK_MASK;
		}
		*res++ = r;
	}
}

// ----------------------------------------------------------------------
// Create and issue a read or write SPI command.
// ----------------------------------------------------------------------
static	void	spi_rw ( void )
{
	uint_t	a;

	a = address++;
	if	( cmd0 & 0x80 )
	{	// eeprom
		a <<= 1;
	}
	cmd[0] = cmd0;
	if	( a & 1 )
	{
		cmd[0] |= 0x08;
	}
	cmd[1] = a >> 9;
	cmd[2] = a >> 1;
	spi( cmd, res, 4 );
}

// ----------------------------------------------------------------------
// Handle a non-standard SETUP packet.
// ----------------------------------------------------------------------
extern	byte_t	usb_setup ( byte_t data[8] )
{
	byte_t	bit;
	byte_t	mask;
	byte_t*	addr;
	byte_t	req;

	// Generic requests
	req = data[1];
	if	( req == USBTINY_ECHO )
	{
		return 8;
	}
	addr = (byte_t*) (int) data[4];
	bit = data[2] & 7;
	mask = 1 << bit;
	if (req == USBTINY_SET) {
	  PORT |= mask;
	  return 0;
	}
	if (req == USBTINY_CLR) {
	  PORT &= ~ mask;
	  return 0;
	}
	if (req == USBTINY_WRITE) {
	  PORT = data[2];
	  return 0;
	}
	if (req == USBTINY_READ) {
	  data[0] = PIN;
	  return 1;
	}
	if (req == USBTINY_DDRWRITE) {
	  DDR = data[2];
	}
	// Programming requests
	if	( req == USBTINY_POWERUP )
	{
		sck_period = data[2];
		mask = POWER_MASK;
		if	( data[4] )
		{
			mask |= RESET_MASK;
		}
		PORTD &= ~_BV(4);
		DDR  = POWER_MASK | RESET_MASK | SCK_MASK | MOSI_MASK;
		PORT = mask;
		return 0;
	}
	if	( req == USBTINY_POWERDOWN )
	{
	  //PORT |= RESET_MASK;
		DDR  = 0x00;
		PORT = 0x00;
		PORTD |= _BV(4);
		return 0;
	}
	if	( ! PORT )
	{
		return 0;
	}
	if	( req == USBTINY_SPI )
	{
	  spi( data + 2, data + 0, 4 );
		return 4;
	}
	if	( req == USBTINY_SPI1 )
	{
	  spi( data + 2, data + 0, 1 );
		return 1;
	}
	if	( req == USBTINY_POLL_BYTES )
	{
		poll1 = data[2];
		poll2 = data[3];
		return 0;
	}
	address = * (uint_t*) & data[4];
	if	( req == USBTINY_FLASH_READ )
	{
		cmd0 = 0x20;
		return 0xff;	// usb_in() will be called to get the data
	}
	if	( req == USBTINY_EEPROM_READ )
	{
		cmd0 = 0xa0;
		return 0xff;	// usb_in() will be called to get the data
	}
	timeout = * (uint_t*) & data[2];
	if	( req == USBTINY_FLASH_WRITE )
	{
		cmd0 = 0x40;
		return 0;	// data will be received by usb_out()
	}
	if	( req == USBTINY_EEPROM_WRITE )
	{
		cmd0 = 0xc0;
		return 0;	// data will be received by usb_out()
	}
	return 0;
}

// ----------------------------------------------------------------------
// Handle an IN packet.
// ----------------------------------------------------------------------
extern	byte_t	usb_in ( byte_t* data, byte_t len )
{
	byte_t	i;

	for	( i = 0; i < len; i++ )
	{
		spi_rw();
		data[i] = res[3];
	}
	return len;
}

// ----------------------------------------------------------------------
// Handle an OUT packet.
// ----------------------------------------------------------------------
extern	void	usb_out ( byte_t* data, byte_t len )
{
	byte_t	i;
	uint_t	usec;
	byte_t	r;

	for	( i = 0; i < len; i++ )
	{
		cmd[3] = data[i];
		spi_rw();
		cmd[0] ^= 0x60;	// turn write into read
		for	( usec = 0; usec < timeout; usec += 32 * sck_period )
		{	// when timeout > 0, poll until byte is written
		  spi( cmd, res, 4 );
			r = res[3];
			if	( r == cmd[3] && r != poll1 && r != poll2 )
			{
				break;
			}
		}
	}
}
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

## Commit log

2013-04-22 Adding driver, firmware and hardware files.
    [AVR-Pocket-Programmer.brd, AVR-Pocket-Programmer.sch, ir.sch]
2013-10-07 Adding Zadig to drivers folder for easier installation on Windows 8
2013-12-03 QC Revision
    1.) 0402 to 0603 footprints
    2.) OSHW logo
    3.) Switch date code to rev code
    Will be adding new PTC footprint soon
    [AVR-Pocket-Programmer.brd, AVR-Pocket-Programmer.sch]
2013-12-04 QC Revision - second round
    In addition to the three previous changes:
    1.) Updated PTC footprint
    2.) General schematic cleanup
    3.) OSHW and Creative Commons info
    [AVR-Pocket-Programmer.brd, AVR-Pocket-Programmer.sch]
2014-01-15 Created Giant and Regular Panels
    [AVR-Pocket-Programmer-GiantPanel-v11.brd, AVR-Pocket-Programmer-Panel-v11.brd]
2014-05-11 Added Case STL Files
    These STL files can be 3d printed, and provide some protection for the
    programmer.
    [avr.STL, lid.STL]
2014-05-13 Modifying repo structure and updating README.
    [avr.STL, lid.STL]
2015-08-27 Replaced old drivers with the newer signed version
2016-01-04 re-created panel v11, more strength
    [AVR-Pocket-Programmer-GiantPanel-v11.brd, AVR-Pocket-Programmer-Panel-v11.brd, AVR-Pocket-Programmer_Panel_v11a.brd]

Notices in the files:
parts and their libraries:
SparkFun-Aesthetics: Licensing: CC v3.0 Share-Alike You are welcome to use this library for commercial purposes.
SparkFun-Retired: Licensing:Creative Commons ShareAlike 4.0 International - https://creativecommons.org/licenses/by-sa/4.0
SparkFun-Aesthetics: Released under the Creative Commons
